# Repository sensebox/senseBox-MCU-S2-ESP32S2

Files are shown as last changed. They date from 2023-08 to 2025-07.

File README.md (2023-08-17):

# senseBoxMCU-S2 ESP32S2

# Erste Schritte

## Vorbereitung der Arduino IDE
Für den ESP32 werden von der Arduino-DIE zusätzliche Repositories benötigt:
Unter Datei -> Voreinstellungen muss unter Zusätzliche Boardverwalter-URLs 
```
https://raw.githubusercontent.com/espressif/arduino-esp32/gh-pages/package_esp32_dev_index.json
```
eingetragen werden. Anschließend muss unter Werkzeuge  Board: …  Boardverwalter… das Tool esp32 by Espressif Systems installiert werden.
Nachdem alles geladen wurde, muss man unter Werkzeuge das Board ESP32S2 Dev Module auswählen und USB CDC On Boot auf Enable stellen.
Zur Nutzung des UF2-Bootloaders müssen die UF2-Dateien von der Arduino-DIE erzeugt werden. Eine ausführliche Anleitung, wie die Arduino-IDE hierfür angepasst werden muss, findet sich unter
https://blog.adafruit.com/2021/09/17/automated-generation-of-bin-hex-uf2-files-for-arduino-continuous-integration/

### Installieren des UF2-Bootloaders
Eine Anleitung zur Installation des UF2-Bootloaders findet sich unter:
https://learn.adafruit.com/adafruit-metro-esp32-s2/install-uf2-bootloader

### Demo Codes

**Abstandssensor**
Es wird aus der Arduino-Bibliothek das Bifrost library for HC-SR04 Modul benötigt.
Es handelt sich hier um das angepasste Beispiel aus dem Modul, hier wurden lediglich die Pins für den IO2/IO3 Stecker angepasst und das Aktivieren der IO-Ports hinzugefügt.

**GPIO** 
Es werden keine besonderen Module benötigt.
Im Code werden die IO-Ports aktiviert und die beiden GPIOs 6 und 7 im Sekundentakt ein- und ausgeschaltet.

**IMU-Sensor ICM-20948**
Es wird zusätzlich das ICM20948_WE Modul benötigt
Dies ist das angepasste Modul aus der Beispielsammlung. Es wurden die I2C-IOs angepasst.

**Lichtsensor / Photo-Diode**
In diesem Beispiel wird die fest verbaute IN-S63DTLS analog gemessen. Besonders hier ist hier, dass PD_ENABLE Active-High ist, anstatt Active-Low wie in den anderen Beispielen.
Die Photodiode wird einmal pro Sekunde gemessen und der Bytewert ist über den seriellen Monitor von Arduino ausgebbar.
Die gemessene Spannung ist abhängig vom Photostrom der Photodiode:
V_Out=I_Photo/R
mit 
R=33kΩ
Bei normalem Umgebungslicht sollte der Bytewert etwa 200-500 betragen, bei direkter Sonneneinstrahlung liegt der Wert typisch bei 1000-2000. Bei direkter Bestrahlung mit einer weißen Hochleistungs-LED kann der Wert bis zum maximalen Wert von 4095 steigen. Die folgende Abbildung aus dem Datenblatt der Photodiode zeigt den Zusammenhang zwischen Lichtintensität und Photostrom:

**RGB-LED**
Es wird zusätzlich das Freenove_WS2812_Lib_for_ESP32 Modul benötigt.
Dieses Beispiel lässt die verbaute WS2812-LED im Sekundentakt alternativ rot, grün oder blau leuchten.

**SD-Card**
Das SD-Modul ist automatisch installiert.
Dieses ist das angepasste Beispiel aus dem Modul, es wurde die Aktivierung der Stromversorgung der SD-Karte hinzugefügt. Zusätzlich mussten die GPIOs für SPI angepasst werden.

**WLAN Client**
Das genutzte Wifi Modul ist automatisch installiert. 
Dieses Beispiel versucht eine WLAN-Verbindung aufzubauen und dann einen Webserver zu erreichen.

## Reset Button 
Das Board kann zurück in den Bootloader Modus gebracht werden, wenn der `Reset` Knopf gedrückt wird und der `Boot-Switch`-Button gleichzeitig gehalten wird.

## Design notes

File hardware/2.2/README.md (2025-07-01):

The following should be noted regarding these schematics:
- The chip name is  actually "ESP32-S2-MINI-1-N4R2"
- The UART_ENABLE Pin is not used anymore for enabeling the UART (UART is always enabled now). It is instead used internally for the PSRAM

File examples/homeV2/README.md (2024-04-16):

# HomeV2 Sketch Beta 

## Get started
 - Edit your ID's in the `ids.h` file 
 - Upload the sketch 
 - Let senseBox start and connect to its WiFi Access Point with the following credentials : SSID: `senseBox-AccessPoint` PW: `123456789`
 - With your connected device open `192.168.4.1` in your browser
 - Input your SSID and password into the form and click on "Verbinden" 
 - Your SSID and password will be uploaded onto the senseBox and saved on SD card (encrypted) the MCU should restart after some seconds and try to connect to the new WiFi 

## Future work 
 - Make sensors optional (i.e. work with #define statements)
 - Format to `.tpl` code for the templater
 - Have non SD version
 - Incorporate additional sensors

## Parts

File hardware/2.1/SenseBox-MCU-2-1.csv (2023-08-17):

Qty | Value | Device | Package | Parts | Description | BE# | CURRENT | DIELECTRIC | INDUCTANCE | POWER | TEMPERATURE_COEFFICIENT | TOLERANCE | VALUE | VOLTAGE
3 |  | PM_ASSEMBLY | PM1 | PM1, PM2, PM3 | Passing Marker | 0
2 | 0R | R_0R_0402N | 0402N | R4, R5 | Resistor | 1054 |  |  |  |  |  |  | 0R
1 | 0ZCH0150FF2E | FUSE-2PIN_1.5A_1210N | 1210N | F1 | Fuse with two Pins. | 2289 | 1.5 |  |  |  |  |  | 0ZCH0150FF2E
6 | 100K | R_100K_0402N | 0402N | R10, R11, R12, R14, R15, R16 | Resistor | 615 |  |  |  | 0.063 | 100 | 1% | 100K | 50
5 | 100n | C_100N_0402N | 0402N | C8, C16, C19, C20, C28 | Capacitor | 756 |  | X7R |  |  |  |  | 100n | 16
2 | 10K | RN4_10K_CAY16 | CAY16 | RN5, RN6 | Quad Resistor Net | 196 |  |  |  | 0.062 |  | 5% | 10K | 50
2 | 10K | R_10K_0402N | 0402N | R3, R13 | Resistor | 616 |  |  |  | 0.063 | 100 | 1% | 10K | 50
2 | 10n | C_10N_0402N | 0402N | C22, C27 | Capacitor | 617 |  | X7R |  |  |  |  | 10n | 25
2 | 12p | C_12P_0402N | 0402N | C14, C15 | Capacitor | 754 |  | NPO |  |  |  |  | 12p | 50
2 | 1K | R_1K_0402N | 0402N | R1, R18 | Resistor | 1088 |  |  |  | 0.063 | 100 | 1% | 1K | 50
2 | 1M | R_1M_0402N | 0402N | R8, R9 | Resistor | 1089 |  |  |  | 0.063 | 100 | 1% | 1M | 50
2 | 1X10-2.00-SMT | 1X10_2.00-SMT | 1X10-2.00-SMD | X10, X11 | Pin Header | 2288 |  |  |  |  |  |  | 1X10-2.00-SMT
3 | 1u | C_1U_0402N | 0402N | C9, C12, C13 | Capacitor | 901 |  | X5R |  |  |  |  | 1u | 10
1 | 1u | L_WE-LQS-1U_5040 | 5040 | L1 | Inductor | 2282 | 4.9 |  | 1u |  |  |  | 1u
5 | 22u | C_22U_0805N | 0805N | C1, C2, C7, C17, C18 | Capacitor | 208 |  | X5R |  |  |  |  | 22u | 6V3
1 | 2K | R_2K_0402N | 0402N | R2 | Resistor | 1057 |  |  |  | 0.063 | 100 | 1% | 2K | 50
1 | 2n2 | C_2N2_0402N | 0402N | C21 | Capacitor | 752 |  | X7R |  |  |  |  | 2n2 | 50
1 | 32K768 | CRYSTAL-1GND_1.4X1.5X5.2 | 1.4X1.5X5.2 | XT1 | Crystal with one Ground Terminal | 830 |  |  |  |  |  |  | 32K768
3 | 330R | RN4_330R_CAY16 | CAY16 | RN1, RN3, RN4 | Quad Resistor Net | 483 |  |  |  | 0.062 |  | 5% | 330R | 50
1 | 33K | R_33K_0402N | 0402N | R17 | Resistor | 1428 |  |  |  | 0.063 | 100 | 1% | 33K | 50
1 | 452403012014 | DPDT_WS-SLSV | WS-SLSV | SW1 | Switch - Double Pole, Double Throw | 2294 |  |  |  |  |  |  | 452403012014
6 | 4u7 | C_4U7_0603N | 0603N | C3, C4, C5, C6, C26, C29 | Capacitor | 284 |  | X5R |  |  |  |  | 4u7 | 6V3
2 | 5K1 | R_5K1_0402N | 0402N | R6, R7 | Resistor | 2285 |  |  |  | 0.063 | 100 | 1% | 5K1 | 50
1 | 7427927291 | L_WE-CBF-7427927291_0402N | 0402N | L2 | Inductor | 1925 | 0.3 |  |  |  |  |  | 7427927291
1 | 82400152 | TVS-3-CHANNELS_WE-TVS_SOT563 | SOT563 | D3 | TVS Suppressor Diodes Array | 2015 |  |  |  |  |  |  | 82400152
1 | B4B-PH-SM4-TB | SH-02_B4B-PH-SM4-TB_B4B-PH-SM4-TB | B4B-PH-SM4-TB | X2 | SH Connector | 2370 |  |  |  |  |  |  | B4B-PH-SM4-TB
1 | BE_LOGO_10MM_T | BE_LOGO_10MM_T | BE_TOP_10MM | U$3 | Budelmann Elektronik Logo for pcb print in different sizes. | 0
1 | BM02B-SRSS | SH-02_BM02B-SRSS_BM02B-SRSS | BM02B-SRSS | X9 | SH Connector | 2286 |  |  |  |  |  |  | BM02B-SRSS
6 | BM04B-SRSS | SH-04_BM04B-SRSS_BM04B-SRSS | BM04B-SRSS | X3, X4, X5, X6, X7, X8 | SH Connector | 2287 |  |  |  |  |  |  | BM04B-SRSS
1 | BM05B-SRSS | SH-05_BM05B-SRSS_BM05B-SRSS | BM05B-SRSS | IC9 | SH Connector | 2369 |  |  |  |  |  |  | BM05B-SRSS
2 | DZDH0401DW-7 | DZDH0401DW | SOT363 | IC4, IC5 | Ideal Diode Controller | 2290 |  |  |  |  |  |  | DZDH0401DW-7
1 | ESP32-S2-MINI-1-N4 | ESP32-S2-MINI_ESP32-S2-MINI-1-N4_ESP32-S2-MINI | ESP32-S2-MINI | IC3 | 2.4 GHz Wi-Fi (802.11 b/g/n) module built around ESP32-S2 series of SoCs, Xtensa Single Core 32-bit LX7 Microprocessor | 2275 |  |  |  |  |  |  | ESP32-S2-MINI-1-N4
1 | ICM-42670-P | ICM-42670-P_LGA14_2.5X3 | LGA14_2.5X3 | IC8 | high performance 6-axis MEMS MotionTracking IMU | 2357 |  |  |  |  |  |  | ICM-42670-P
1 | IN-S63DTLS | PHOTODIODE_IN-S63DTLS_0603N | 0603N | D5 | Photo diode | 2296 |  |  |  |  |  |  | IN-S63DTLS
1 | LM66200DRLR | LM66200 | SOT-5X3 | D2 | LM66200 1.6-5V, 2.5A Dual Ideal Diode with Automatic Switchover | 2291 |  |  |  |  |  |  | LM66200DRLR
1 | MCP73831T-2ACI/OT | MCP73831_MCP73831T-2ACI/OT_SOT23-5 | SOT23-5 | IC2 | Miniature Single-Cell, Fully Integrated Li-Ion, Li-Polymer Charge Management Controllers up to 500mA | 2283 |  |  |  |  |  |  | MCP73831T-2ACI/OT
1 | MEM2051-00-195-00-A | SD-CARD2_MEM2051 | MEM2051 | X12 | SD Card with Card Detection (Single Pin Contacting GND) | 2293 |  |  |  |  |  |  | MEM2051-00-195-00-A
1 | MPU-6050 | MPU-6050 | QFN24_4X4 | IC6 | 6-Axis Inertial Measurement Unit Combining a 3-Axis Gyroscope and a 3-Axis Accelerometer | 2297 |  |  |  |  |  |  | MPU-6050
1 | NX3008NBKS | MOSFET-N-DUAL_NX3008NBKS_SOT363 | SOT363 | Q6 | Dual Mosfet | 405 | 0.35 |  |  | 0.3 |  |  | NX3008NBKS | 30
4 | PMV48XP | MOSFET-P_PMV48XP_SOT23' | SOT23 | Q2, Q3, Q4, Q5 | Single P-Channel Mosfet | 271 | 3.5 |  |  |  |  |  | PMV48XP | 20
1 | RP602Z330C-E2-F | RP602_RP602Z330C-E2-F_WLCSP-20-P1 | WLCSP-20-P1 | IC1 | 1.5 A PWM/VFM Buck-Boost DC/DC Converter with Synchronous Rectifier | 2281 |  |  |  |  |  |  | RP602Z330C-E2-F
1 | SIA911ADJ-T1-GE3 | MOSFET-P-DUAL_SIA911ADJ-T1-GE3_POWERPAK-SC70-6 | POWERPAK-SC70-6 | Q1 | Dual Mosfet with Common Drain Pins | 2292 | 4.5 |  |  |  |  |  | SIA911ADJ-T1-GE3 | 20
1 | USB4105-GF-A | USB-C-2.0_USB4105-GF-A_USB4105 | USB4105 | X1 | USB-C Connector with USB 2.0 Support | 2284 |  |  |  |  |  |  | USB4105-GF-A
1 | WS-TASU | TACTILE_SWITCH_WS-TASU | WS-TASU | SW3 | Tactile Switch | 778 |  |  |  |  |  |  | WS-TASU
1 | WS-TRS-6x3.5 | TACTILE_SWITCH_WS-TRS-6X3.5 | WS-TRS-6X3.5 | SW2 | Tactile Switch | 272 |  |  |  |  |  |  | WS-TRS-6x3.5
1 | WS2812B | LED-ADRESSABLE_WS2812B_5050 | 5050 | D4 | Adressable LED with Data-In and Data-Out Pins | 2295 |  |  |  |  |  |  | WS2812B
1 | green | LED_GREEN_0603N | 0603N | D6 | Single LED | 223 |  |  |  |  |  |  | green
2 | opt | C_0402N | 0402N | C10, C11 | Capacitor | 0 |  |  |  |  |  |  | opt
1 | red | LED_RED_0603N | 0603N | D1 | Single LED | 224 |  |  |  |  |  |  | red

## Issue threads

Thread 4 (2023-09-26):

MPU6050 occasionally gives status 2 or 5

PaulaScharf, 2023-09-26:
The onboard mpu occasionally gives status 2 or 5 after the MCU was restarted. This happens with both the MPU6050 and the MPU6050_light library. It is solved by replugging the usb cable between computer and MCU.
The status codes come from the endTransmission call from the Wire library:
status 2: received NACK on transmit of address
status 5: timeout

PaulaScharf, 2023-10-11:
This seems to have been an issue cause by the [MPU6050_light](https://github.com/rfetick/MPU6050_light) library. It doesnt (or rarely) occurs with for example the [Adafruit_MPU6050](https://github.com/adafruit/Adafruit_MPU6050) library.

Closed 2023-10-11.

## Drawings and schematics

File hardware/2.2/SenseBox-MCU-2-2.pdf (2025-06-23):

# and On/Off-Switch USB

A

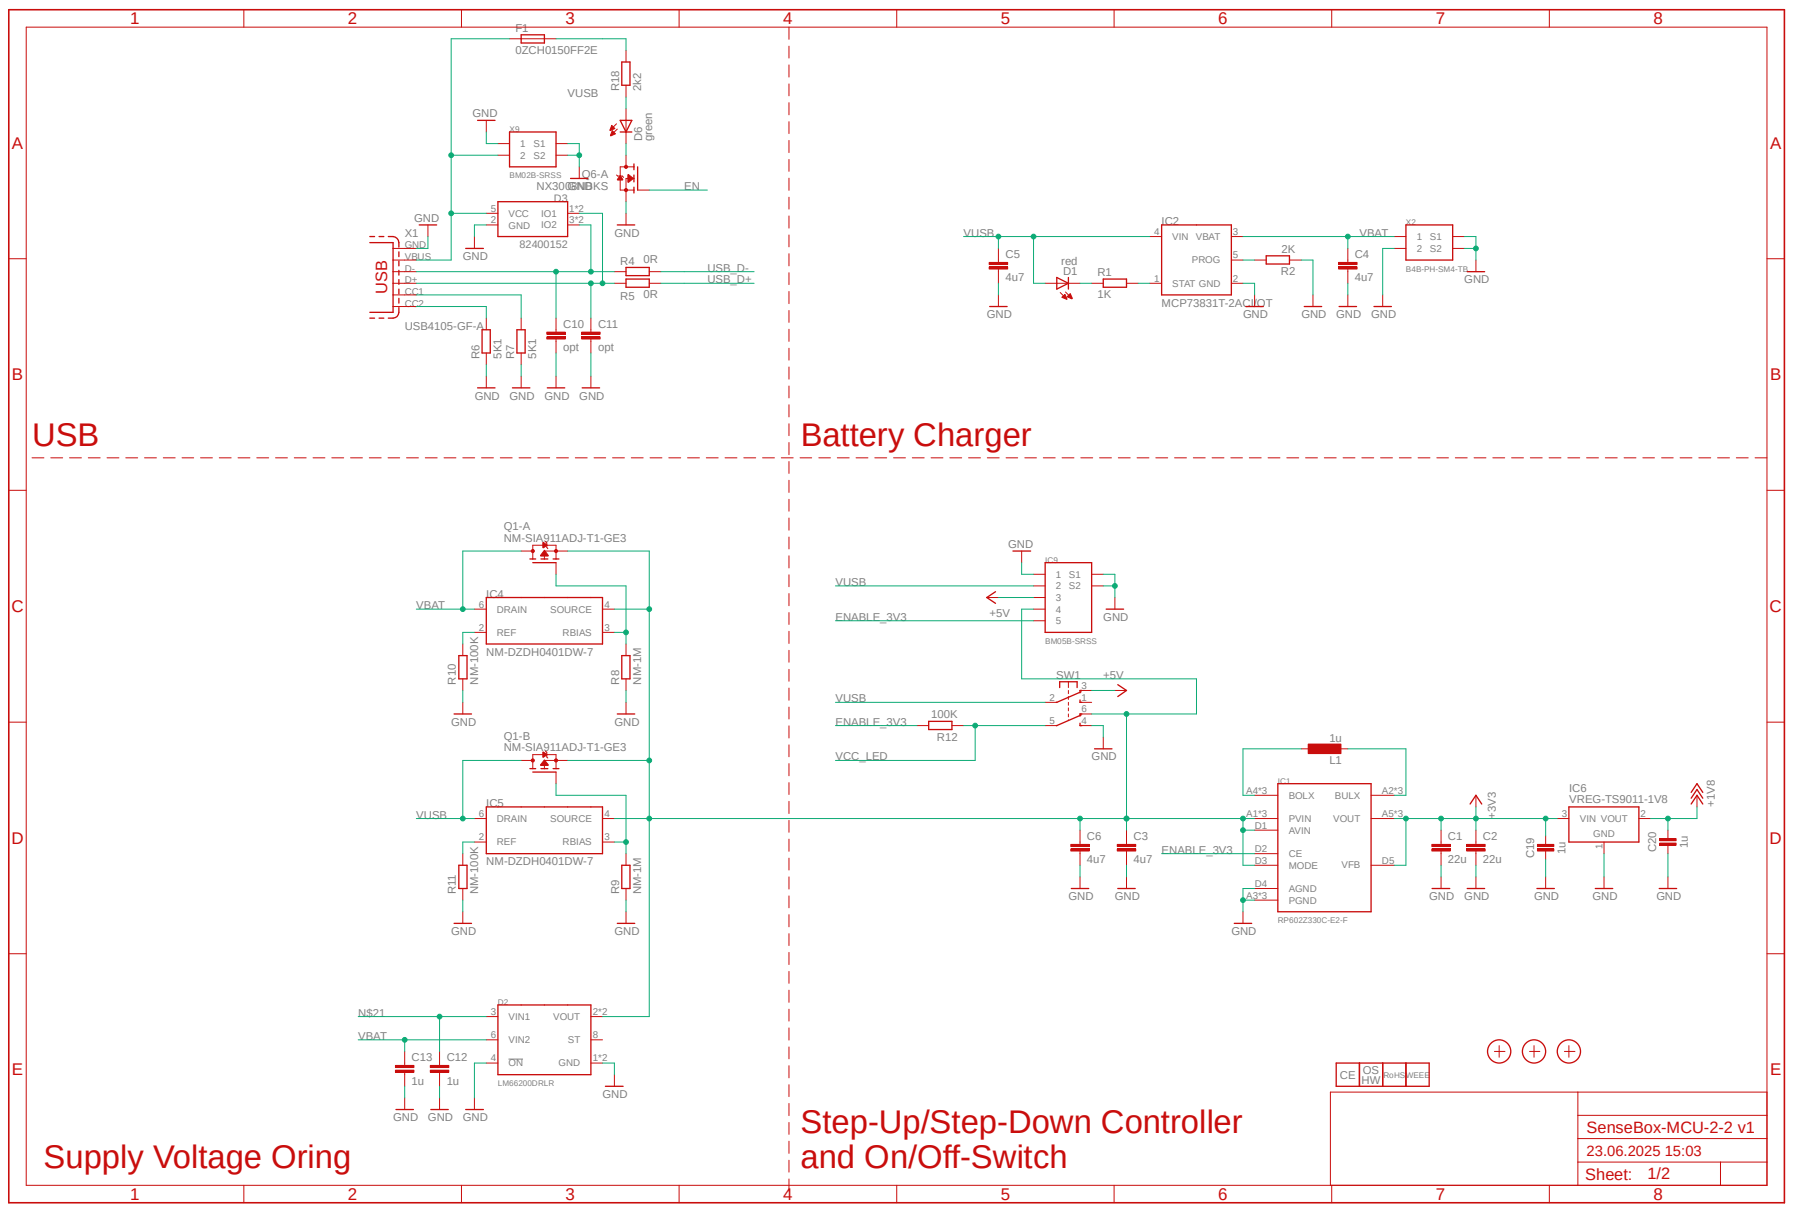
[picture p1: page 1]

D+
CC1

Step-Up/Step-Down Controller

# 1u ¹⁰K ⁺³V³ GND

# GND ¹⁰K ⁺³V³ PMV⁴⁸XP22u

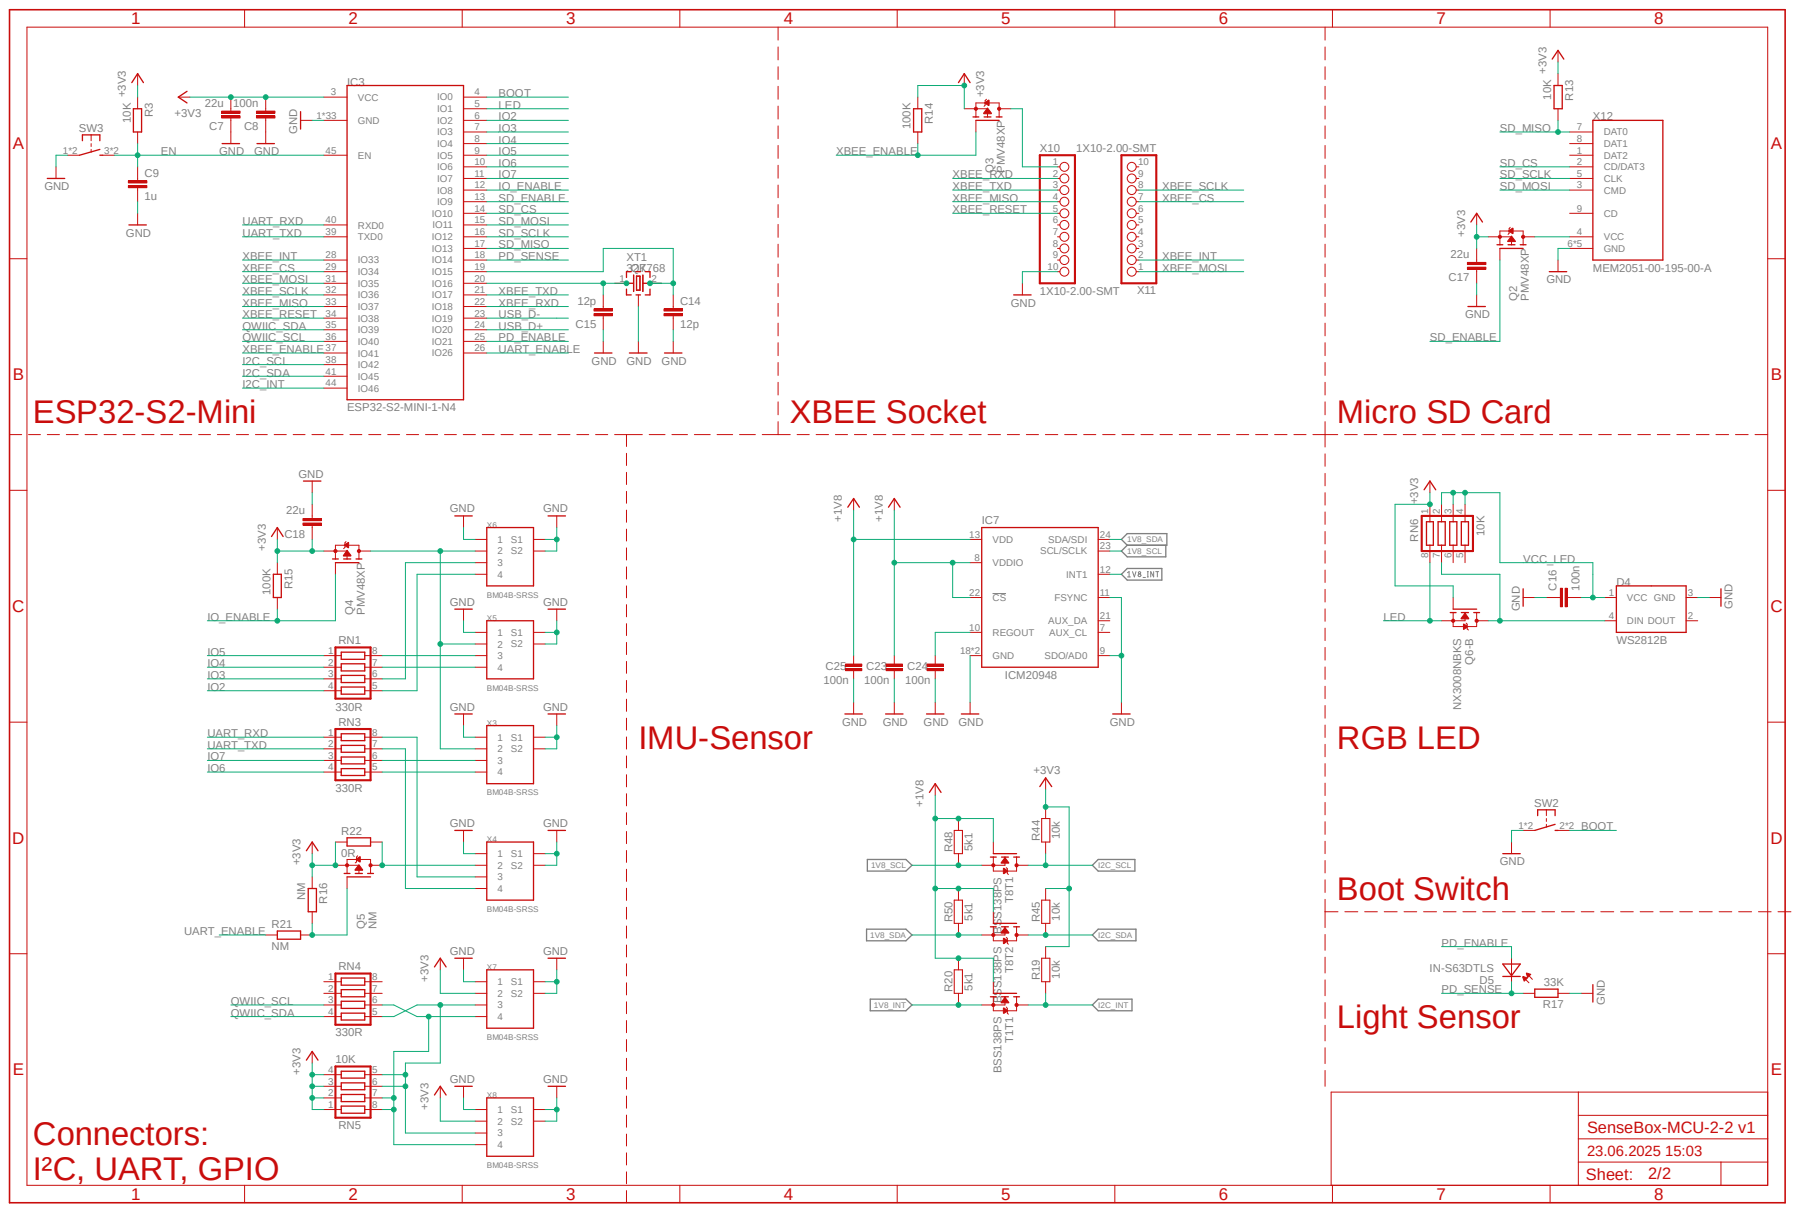
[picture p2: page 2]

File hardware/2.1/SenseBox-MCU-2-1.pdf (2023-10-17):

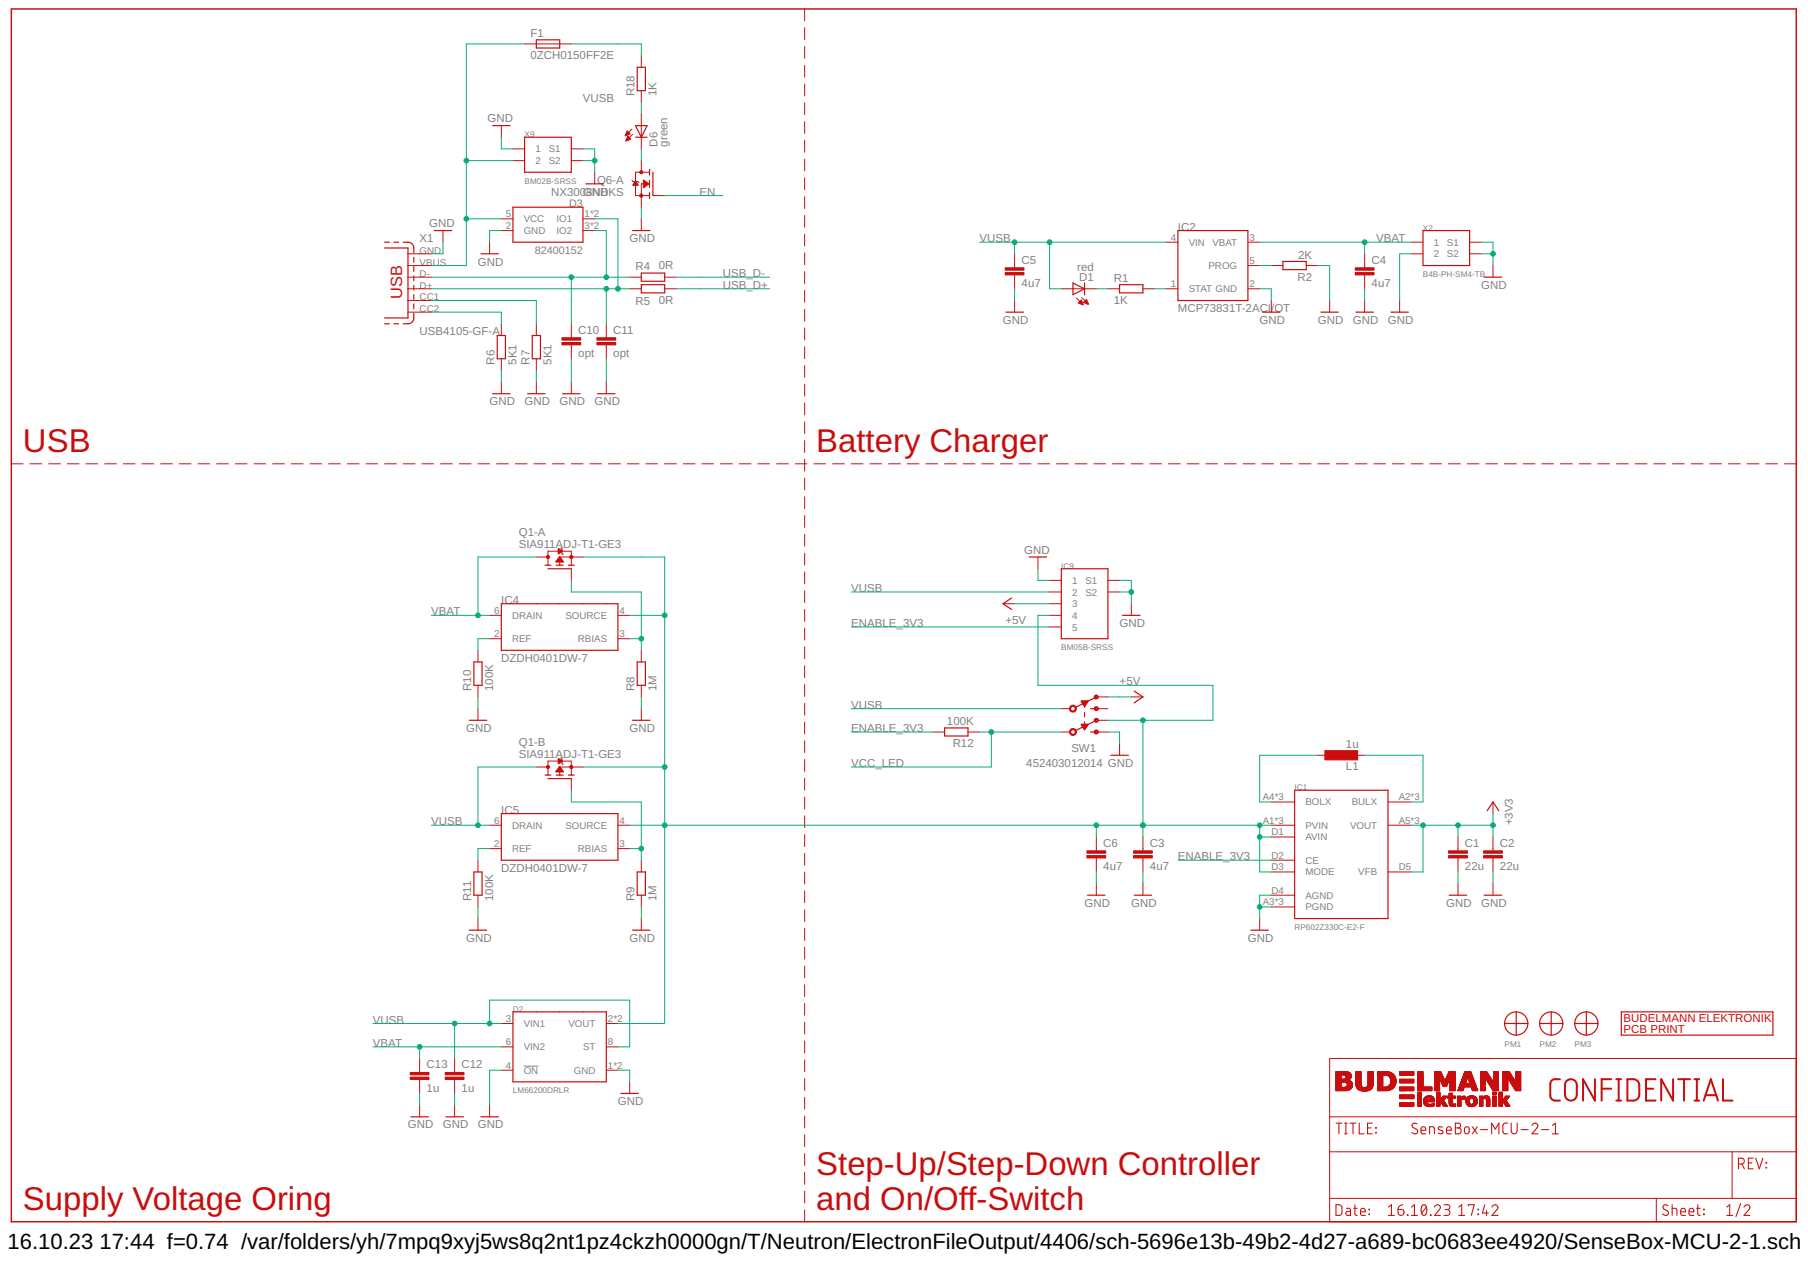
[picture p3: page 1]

B4B-PH-SM4-TBGND GND GND

Step-Up/Step-Down Controller
and On/Off-Switch

16.10.23 17:44 f=0.74 /var/folders/yh/7mpq9xyj5ws8q2nt1pz4ckzh0000gn/T/Neutron/ElectronFileOutput/4406/sch-5696e13b-49b2-4d27-a689-bc0683ee4920/SenseBox-MCU-2-1.sch (Sheet: 1/2)

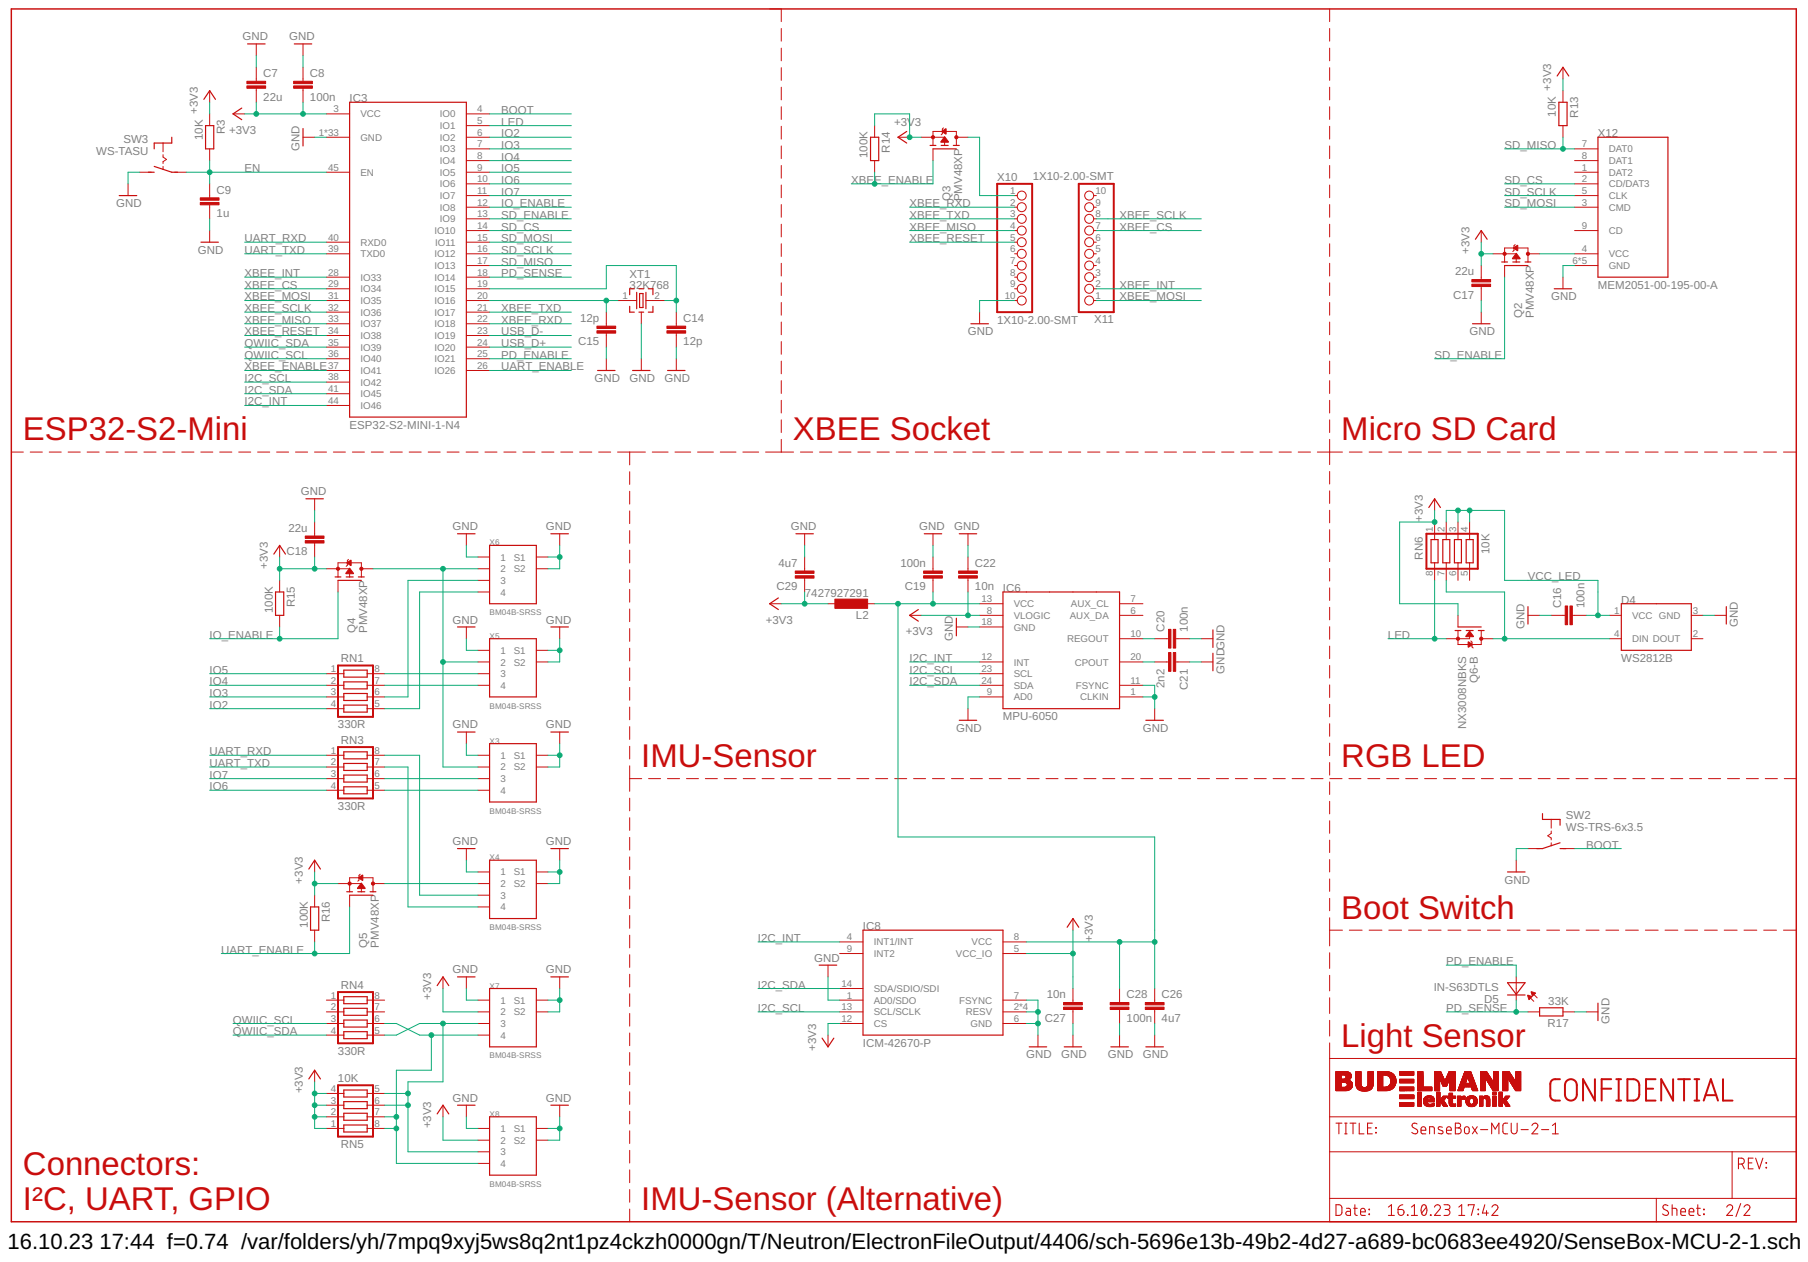
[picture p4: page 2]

+3V3 GND GND GND GND GND GND

16.10.23 17:44 f=0.74 /var/folders/yh/7mpq9xyj5ws8q2nt1pz4ckzh0000gn/T/Neutron/ElectronFileOutput/4406/sch-5696e13b-49b2-4d27-a689-bc0683ee4920/SenseBox-MCU-2-1.sch (Sheet: 2/2)

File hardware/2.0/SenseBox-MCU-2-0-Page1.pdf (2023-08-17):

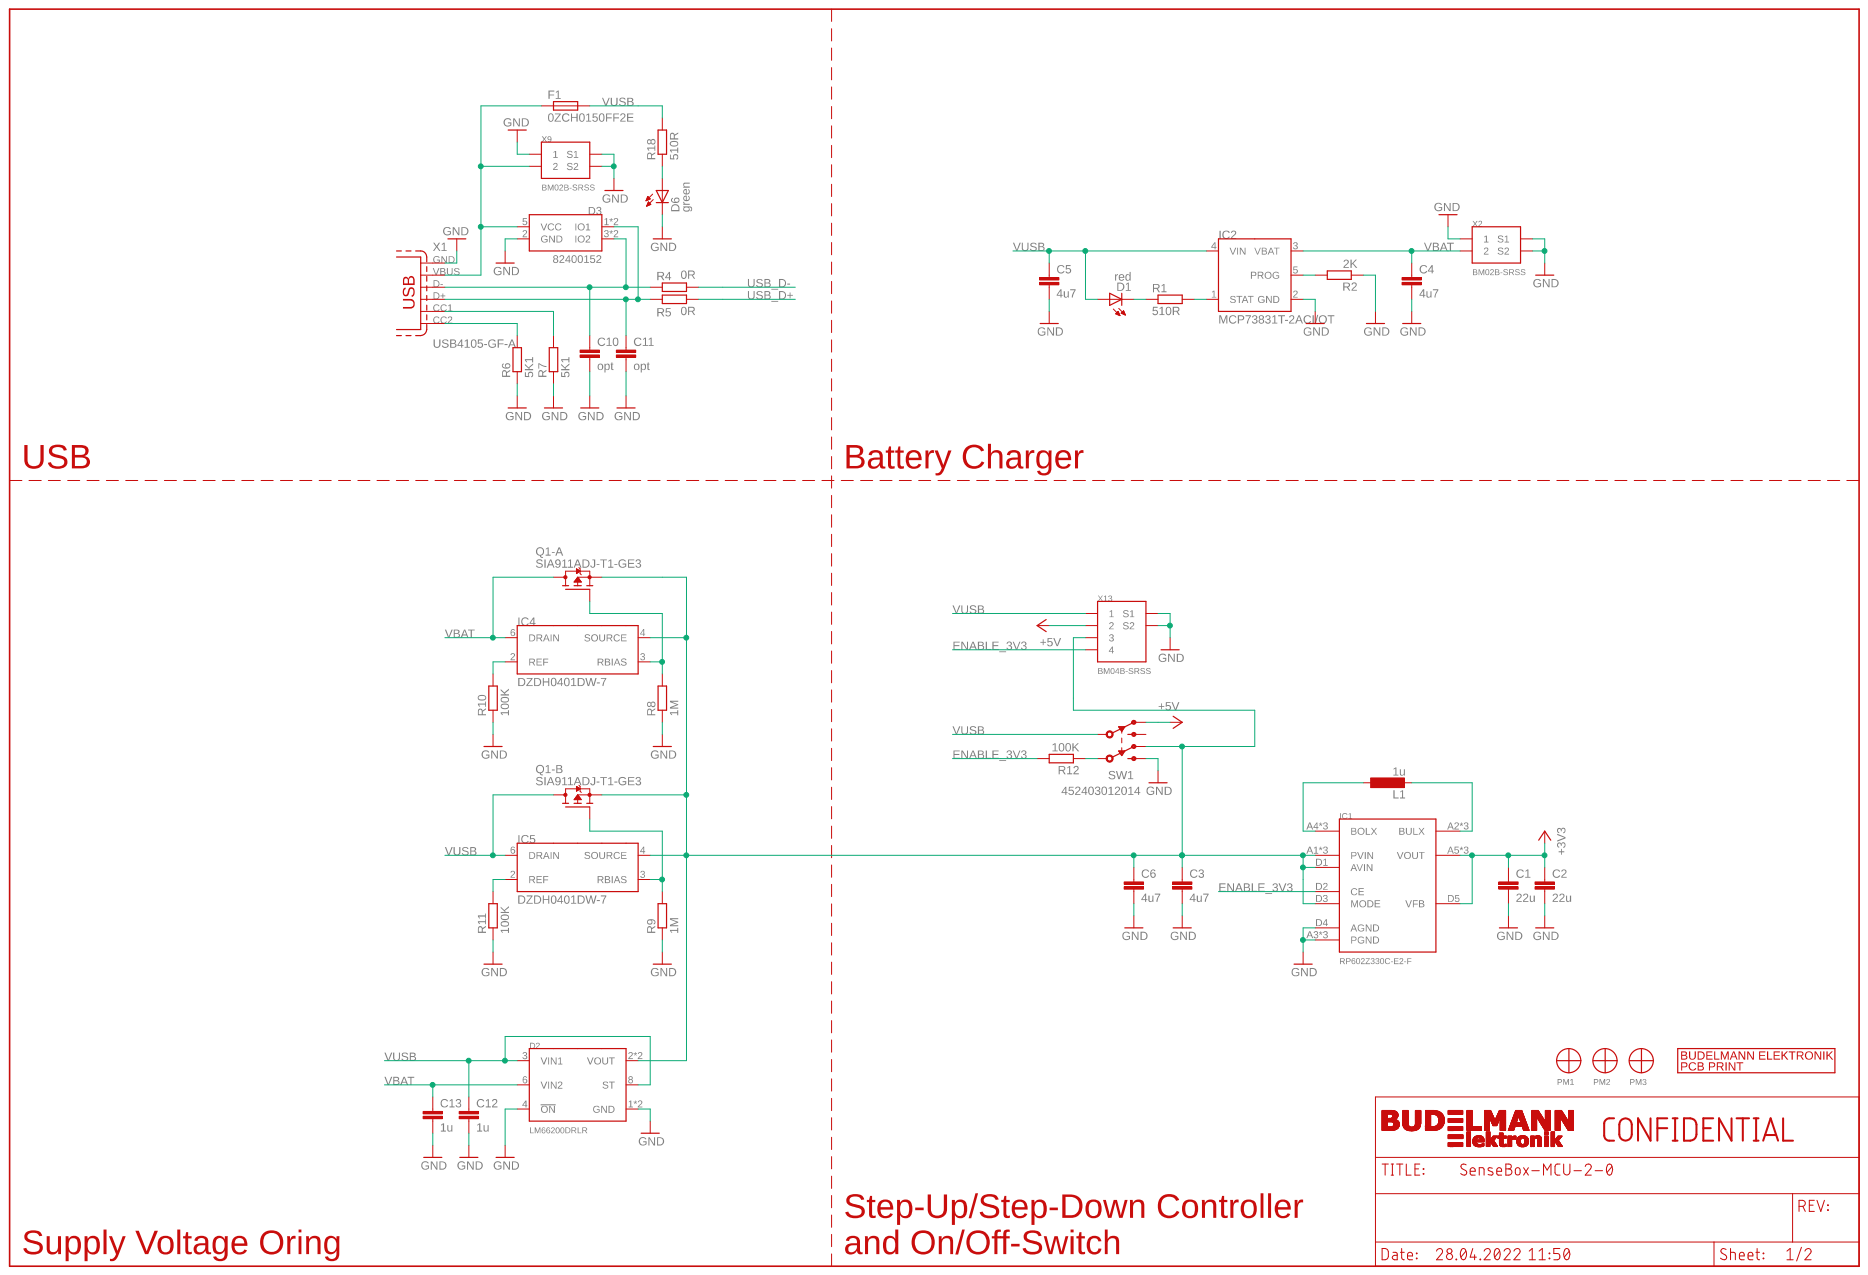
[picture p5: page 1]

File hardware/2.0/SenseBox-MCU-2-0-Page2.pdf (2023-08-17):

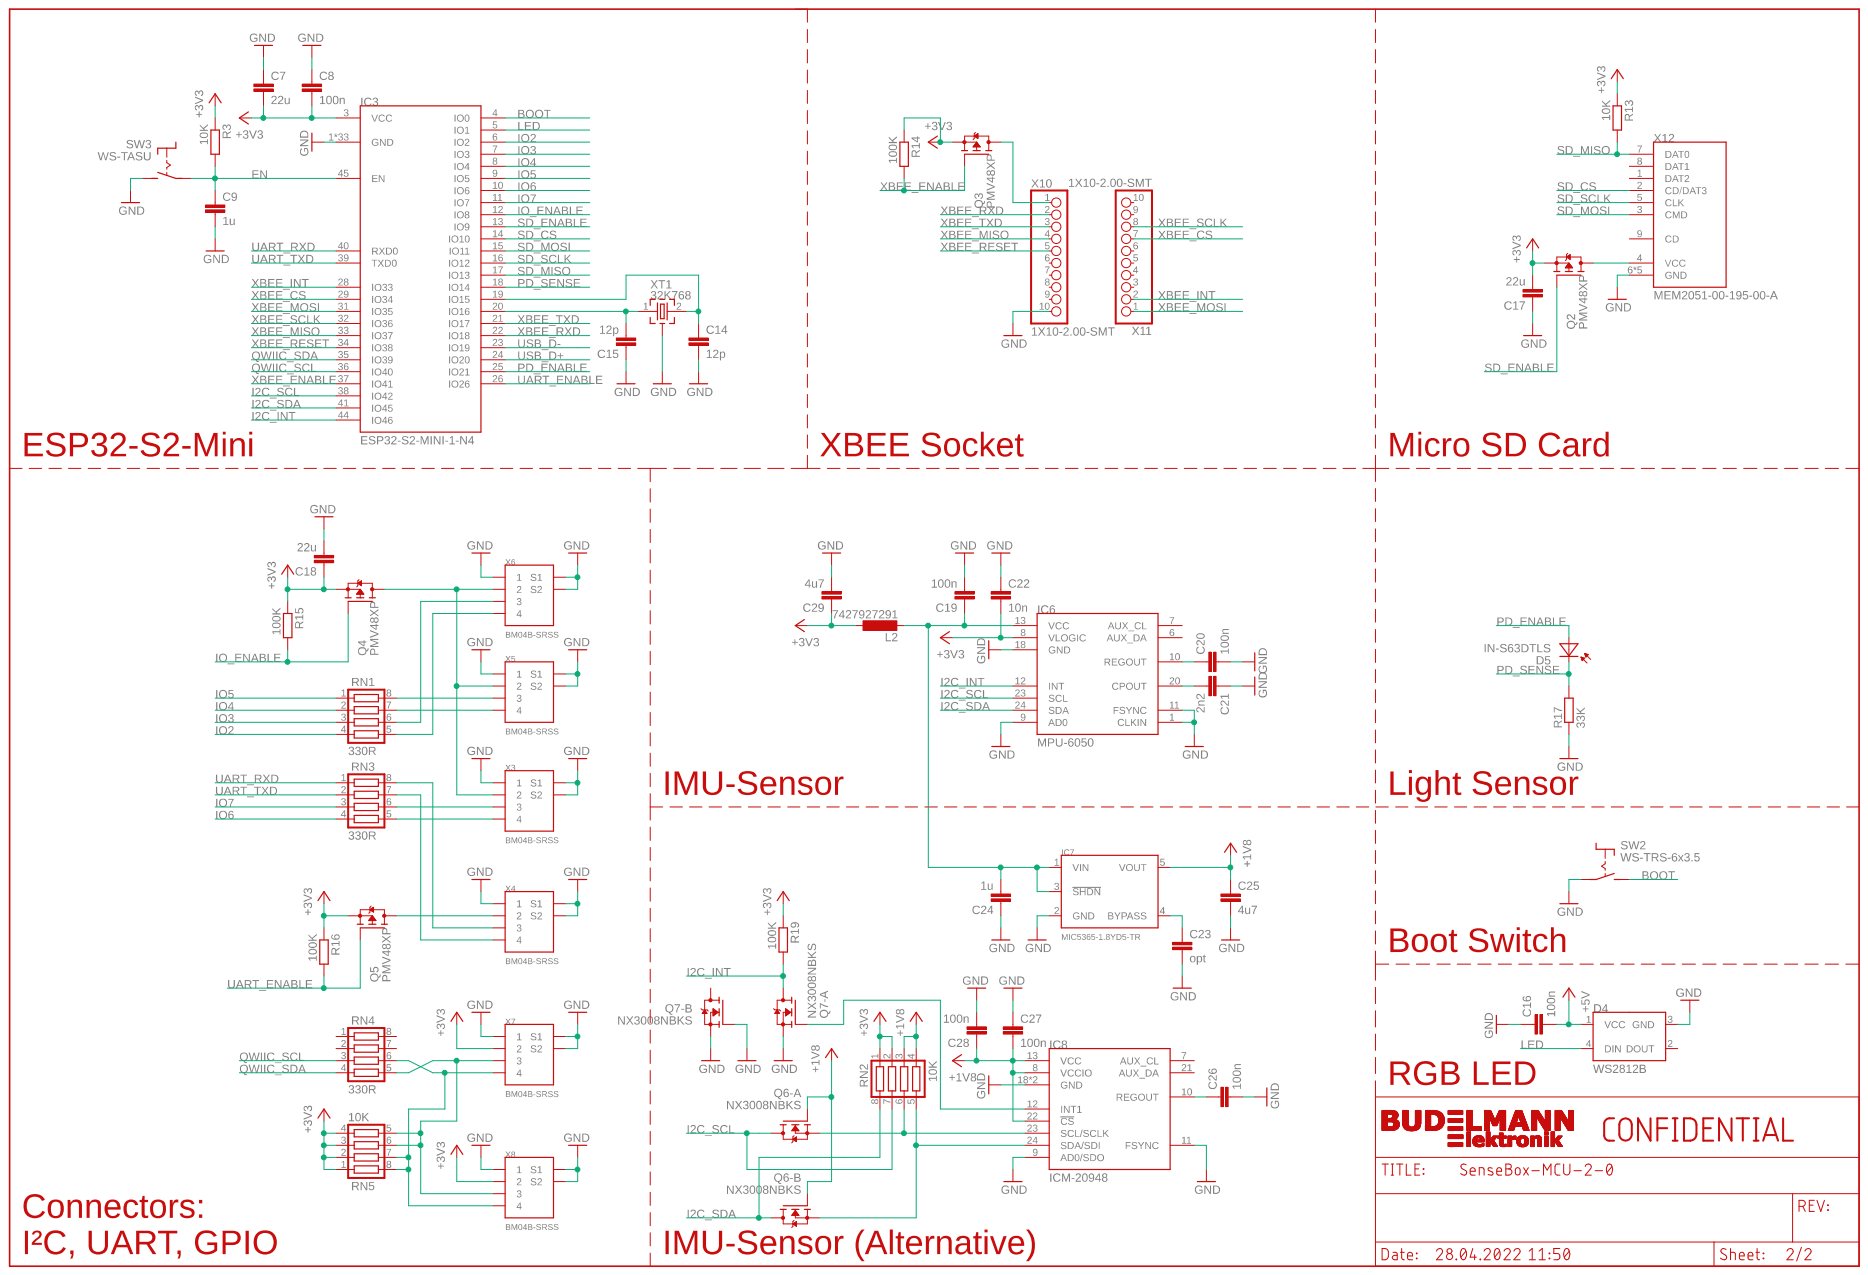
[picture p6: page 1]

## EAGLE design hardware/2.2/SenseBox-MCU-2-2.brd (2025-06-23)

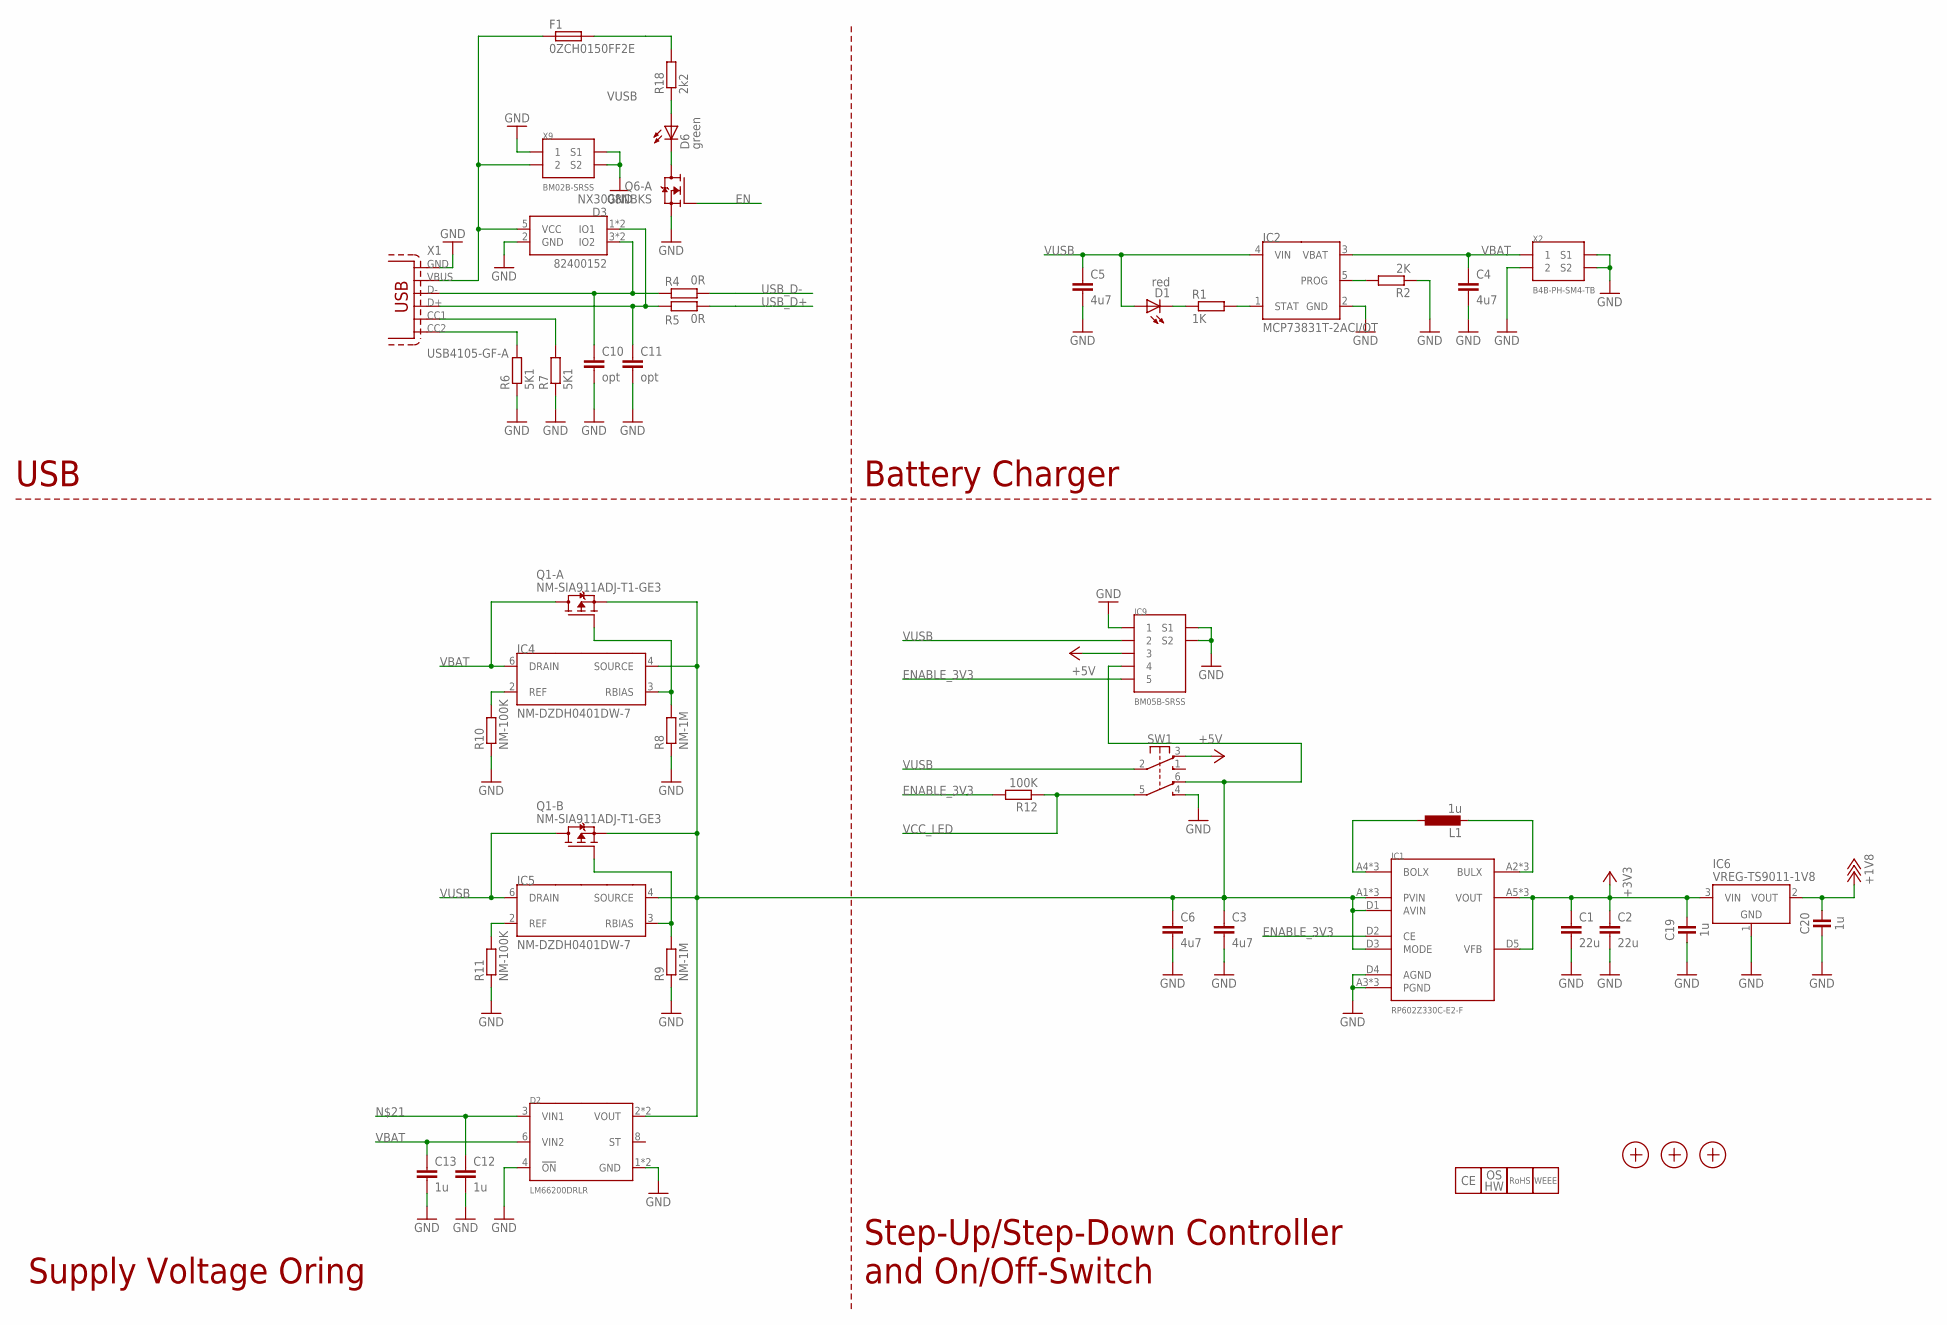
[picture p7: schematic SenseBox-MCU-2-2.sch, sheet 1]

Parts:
C1, C2: 22u; 0805N
C3, C4, C5, C6: 4u7; 0603N
C10, C11: opt; 0402N
C12, C13: 1u; 0402N
C19, C20: 1u; C0402
D1: red; 0603N
D2: LM66200DRLR; SOT-5X3
D3: 82400152; SOT563
D6: green; 0603N
F1: 0ZCH0150FF2E; 1210N
IC1: RP602Z330C-E2-F; WLCSP-20-P1
IC2: MCP73831T-2ACI/OT; SOT23-5
IC4, IC5: NM-DZDH0401DW-7; SOT363
IC6: VREG-TS9011-1V8; SOT23
IC9: BM05B-SRSS
L1: 1u; 5040
LOGO1: LOGO_CE-2; CE_2MM
LOGO2: LOGO_OSHW-2; OSHW_2MM
LOGO3: LOGO_ROHS-2; ROHS_2MM
LOGO4: LOGO_WEEE-4; WEEE_4MM
Q1: NM-SIA911ADJ-T1-GE3; POWERPAK-SC70-6
Q6: NX3008NBKS; SOT363
R1: 1K; 0402N
R2: 2K; 0402N
R4, R5: 0R; 0402N
R6, R7: 5K1; 0402N
R8, R9: NM-1M; 0402N
R10, R11: NM-100K; 0402N
R12: 100K; 0402N
R18: 2k2; 0402N
SW1: SW-2UM-CUS22B; CUS22B
X1: USB4105-GF-A; USB4105
X2: B4B-PH-SM4-TB
X9: BM02B-SRSS
X13, X14, X15: PASSER-07; PASSER_07MM

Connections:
+1V8: C20.2, IC6.2 (VOUT); also elsewhere on the board
+3V3: C1.1, C2.1, C19.2, IC1.A5 (VOUT), IC1.B5 (VOUT), IC1.C5 (VOUT), IC1.D5 (VFB), IC6.3 (VIN); also elsewhere on the board
+5V: IC9.3, SW1.3 (NC1)
EN: Q6.2 (G); also elsewhere on the board
ENABLE_3V3: IC1.D2 (CE), IC9.5, R12.2
GND: C1.2, C2.2, C3.2, C4.2, C5.2, C6.2, C10.2, C11.2, C12.2, C13.2, C19.1, C20.1, D2.1 (GND), D2.4 (!ON), D2.5 (GND), D3.2 (GND), IC1.A3 (PGND), IC1.B3 (PGND), IC1.C3 (PGND), IC1.D4 (AGND), IC2.2 (GND), IC6.1 (GND), IC9.1, IC9.S1, IC9.S2, Q6.1 (S), R2.1, R6.1, R7.1, R8.1, R9.1, R10.1, R11.1, SW1.4 (NO2), X1.A1_B12 (GND), X1.B1_A12 (GND), X1.S1 (GND), X1.S2 (GND), X1.S3 (GND), X1.S4 (GND), X2.2, X2.SH1 (S1), X2.SH2 (S2), X9.1, X9.S1, X9.S2; also elsewhere on the board
unnamed: IC1.A4 (BOLX), IC1.B4 (BOLX), IC1.C4 (BOLX), L1.1
unnamed: IC1.A2 (BULX), IC1.B2 (BULX), IC1.C2 (BULX), L1.2
unnamed: IC2.5 (PROG), R2.2
unnamed: IC4.2 (REF), R10.2
unnamed: D1.C, R1.1
unnamed: IC2.1 (STAT), R1.2
unnamed: C10.1, D3.3 (IO2), D3.4 (IO2), R4.1, X1.A7 (D-), X1.B7 (D-)
unnamed: C11.1, D3.1 (IO1), D3.6 (IO1), R5.1, X1.A6 (D+), X1.B6 (D+)
unnamed: R6.2, X1.B5 (CC2)
unnamed: R7.2, X1.A5 (CC1)
unnamed: D3.5 (VCC), F1.1 (2), X1.A4_B9 (VBUS), X1.B4_A9 (VBUS), X9.2
unnamed: IC5.2 (REF), R11.2
unnamed: IC4.3 (RBIAS), Q1.2 (G), R8.2
unnamed: C3.1, C6.1, D2.2 (VOUT), D2.7 (VOUT), IC1.A1 (PVIN), IC1.B1 (PVIN), IC1.C1 (PVIN), IC1.D1 (AVIN), IC1.D3 (MODE), IC4.4 (SOURCE), IC5.4 (SOURCE), IC9.4, Q1.1 (S), Q1.4 (S), SW1.6 (NC2)
unnamed: IC5.3 (RBIAS), Q1.5 (G), R9.2
unnamed: C12.1, D2.3 (VIN1)
unnamed: D6.A, R18.1
unnamed: D6.C, Q6.6 (D)
USB_D+: R5.2; also elsewhere on the board
USB_D-: R4.2; also elsewhere on the board
VBAT: C4.1, C13.1, D2.6 (VIN2), IC2.3 (VBAT), IC4.6 (DRAIN), Q1.6 (D), Q1.7 (D), X2.1
VCC_LED: R12.1, SW1.5 (C2); also elsewhere on the board
VUSB: C5.1, D1.A, F1.2 (3), IC2.4 (VIN), IC5.6 (DRAIN), IC9.2, Q1.3 (D), Q1.8 (D), R18.2, SW1.2 (C1)

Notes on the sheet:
USB
Battery Charger
Supply Voltage Oring
Step-Up/Step-Down Controller and On/Off-Switch

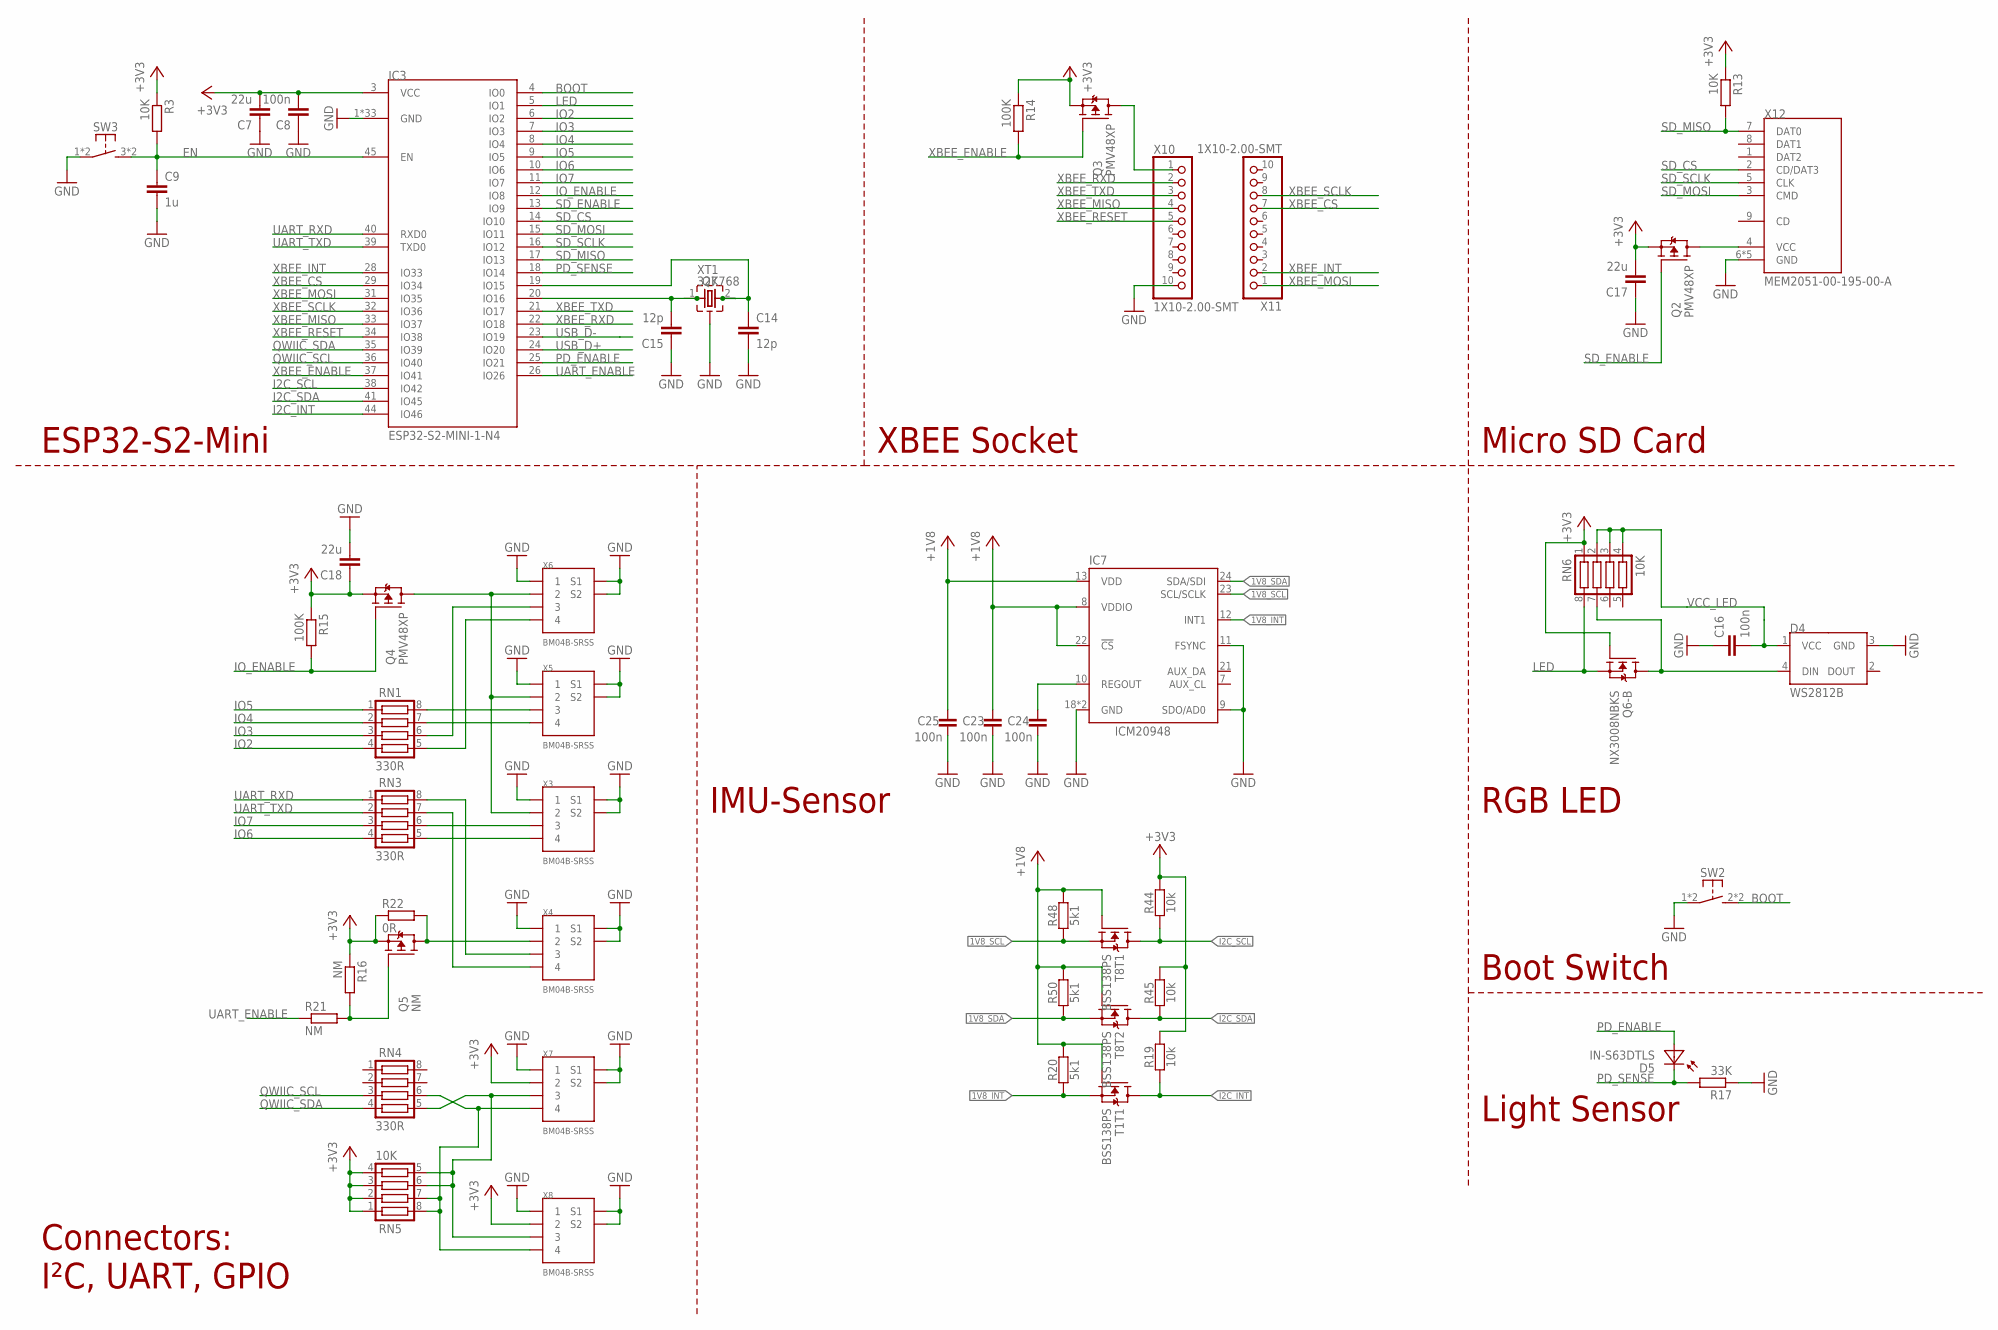
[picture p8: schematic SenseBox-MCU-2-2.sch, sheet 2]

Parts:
C7, C17, C18: 22u; 0805N
C8, C16: 100n; 0402N
C9: 1u; 0402N
C14, C15: 12p; 0402N
C23, C24, C25: 100n; C0402
D4: WS2812B; 5050
D5: IN-S63DTLS; 0603N
IC3: ESP32-S2-MINI-1-N4; ESP32-S2-MINI
IC7: ICM20948; QFN24-3X3
Q2, Q3, Q4: PMV48XP; SOT23
Q5: NM; SOT23
Q6: NX3008NBKS; SOT363
Q7: CRYSTAL-ZM315; CRYSTAL_ZM315
R3, R13: 10K; 0402N
R14, R15: 100K; 0402N
R16, R21: NM; 0402N
R17: 33K; 0402N
R19, R44, R45: 10k; C0402
R20, R48, R50: 5k1; C0402
R22: 0R; 0402N
RN1, RN3, RN4: 330R; CAY16
RN5, RN6: 10K; CAY16
SW2: SW-TACTILE-TL3365; TL3365
SW3: SW-TACTILE-PTS840P; PTS840P
T1, T8: BSS138PS; SOT363
X3, X4, X5, X6, X7, X8: BM04B-SRSS
X10, X11: 1X10-2.00-SMT; 1X10-2.00-SMD
X12: MEM2051-00-195-00-A; MEM2051
XT1: 32K768; 1.4X1.5X5.2

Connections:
1V8_INT: IC7.12 (INT1), R20.1, T1.1 (S)
1V8_SCL: IC7.23 (SCL/SCLK), R48.1, T8.1 (S)
1V8_SDA: IC7.24 (SDA/SDI), R50.1, T8.4 (S)
+1V8: C23.2, C25.2, IC7.8 (VDDIO), IC7.13 (VDD), IC7.22 (!CS), R20.2, R48.2, R50.2, T1.2 (G), T8.2 (G), T8.5 (G); also elsewhere on the board
+3V3: C7.2, C8.2, C17.2, C18.1, IC3.3 (VCC), Q2.2 (S), Q3.2 (S), Q4.2 (S), Q5.2 (S), Q6.5 (G), R3.1, R13.1, R14.1, R15.1, R16.1, R19.2, R22.1, R44.2, R45.2, RN5.1, RN5.2, RN5.3, RN5.4, RN6.1, X7.2, X8.2; also elsewhere on the board
BOOT: IC3.4 (IO0), SW2.2 (S1), SW2.3 (S1)
EN: C9.1, IC3.45 (EN), R3.2, SW3.3 (S1), SW3.4 (S1); also elsewhere on the board
GND: C7.1, C8.1, C9.2, C14.2, C15.1, C16.1, C17.1, C18.2, C23.1, C24.1, C25.1, D4.3 (GND), IC3.1 (GND), IC3.2 (GND), IC3.30 (GND), IC3.42 (GND), IC3.43 (GND), IC3.46 (GND), IC3.47 (GND), IC3.48 (GND), IC3.49 (GND), IC3.50 (GND), IC3.51 (GND), IC3.52 (GND), IC3.53 (GND), IC3.54 (GND), IC3.55 (GND), IC3.56 (GND), IC3.57 (GND), IC3.58 (GND), IC3.59 (GND), IC3.60 (GND), IC3.61 (GND), IC3.62 (GND), IC3.63 (GND), IC3.64 (GND), IC3.65 (GND), IC3.66 (GND), IC3.67 (GND), IC3.68 (GND), IC3.69 (GND), IC3.70 (GND), IC3.71 (GND), IC3.72 (GND), IC3.73 (GND), IC7.9 (SDO/AD0), IC7.11 (FSYNC), IC7.18 (GND), IC7.20 (GND), R17.1, SW2.1, SW2.4 (P1), SW3.1, SW3.2 (P1), X3.1, X3.S1, X3.S2, X4.1, X4.S1, X4.S2, X5.1, X5.S1, X5.S2, X6.1, X6.S1, X6.S2, X7.1, X7.S1, X7.S2, X8.1, X8.S1, X8.S2, X10.10, X12.6 (GND), X12.S1 (GND), X12.S2 (GND), X12.S3 (GND), X12.S4 (GND), XT1.3 (GND); also elsewhere on the board
I2C_INT: IC3.44 (IO46), R19.1, T1.6 (D)
I2C_SCL: IC3.38 (IO42), R44.1, T8.6 (D)
I2C_SDA: IC3.41 (IO45), R45.1, T8.3 (D)
IO2: IC3.6 (IO2), RN1.4
IO3: IC3.7 (IO3), RN1.3
IO4: IC3.8 (IO4), RN1.2
IO5: IC3.9 (IO5), RN1.1
IO6: IC3.10 (IO6), RN3.4
IO7: IC3.11 (IO7), RN3.3
IO_ENABLE: IC3.12 (IO8), Q4.1 (G), R15.2
LED: IC3.5 (IO1), Q6.4 (S), RN6.8
unnamed: RN1.6, X6.3
unnamed: C15.2, IC3.20 (IO16), Q7.1, XT1.1
unnamed: C14.1, IC3.19 (IO15), Q7.2, XT1.2
unnamed: D4.4 (DIN), Q6.3 (D), RN6.7
unnamed: Q4.3 (D), X3.2, X5.2, X6.2
unnamed: Q2.3 (D), X12.4 (VCC)
unnamed: Q3.3 (D), X10.1
unnamed: Q5.3 (D), R22.2, X4.2
unnamed: RN1.5, X6.4
unnamed: RN1.8, X5.3
unnamed: RN1.7, X5.4
unnamed: RN3.5, X3.4
unnamed: RN3.6, X3.3
unnamed: RN3.8, X4.3
unnamed: RN3.7, X4.4
unnamed: RN4.6, RN5.7, RN5.8, X7.4, X8.4
unnamed: RN4.5, RN5.5, RN5.6, X7.3, X8.3
PD_ENABLE: D5.A, IC3.25 (IO21)
PD_SENSE: D5.C, IC3.18 (IO14), R17.2
QWIIC_SCL: IC3.36 (IO40), RN4.3
QWIIC_SDA: IC3.35 (IO39), RN4.4
REGOUT1: C24.2, IC7.10 (REGOUT)
SD_CS: IC3.14 (IO10), X12.2 (CD/DAT3)
SD_ENABLE: IC3.13 (IO9), Q2.1 (G)
SD_MISO: IC3.17 (IO13), R13.2, X12.7 (DAT0)
SD_MOSI: IC3.15 (IO11), X12.3 (CMD)
SD_SCLK: IC3.16 (IO12), X12.5 (CLK)
UART_ENABLE: IC3.26 (IO26), R21.1
UART_ENABLE1: Q5.1 (G), R16.2, R21.2
UART_RXD: IC3.40 (RXD0), RN3.1
UART_TXD: IC3.39 (TXD0), RN3.2
USB_D+: IC3.24 (IO20); also elsewhere on the board
USB_D-: IC3.23 (IO19); also elsewhere on the board
VCC_LED: C16.2, D4.1 (VCC), RN6.2, RN6.3, RN6.4; also elsewhere on the board
XBEE_CS: IC3.29 (IO34), X11.7
XBEE_ENABLE: IC3.37 (IO41), Q3.1 (G), R14.2
XBEE_INT: IC3.28 (IO33), X11.2
XBEE_MISO: IC3.33 (IO37), X10.4
XBEE_MOSI: IC3.31 (IO35), X11.1
XBEE_RESET: IC3.34 (IO38), X10.5
XBEE_RXD: IC3.22 (IO18), X10.2
XBEE_SCLK: IC3.32 (IO36), X11.8
XBEE_TXD: IC3.21 (IO17), X10.3

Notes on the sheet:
Connectors: I²C, UART, GPIO
IMU-Sensor
Light Sensor
Boot Switch
XBEE Socket
Micro SD Card
ESP32-S2-Mini
RGB LED

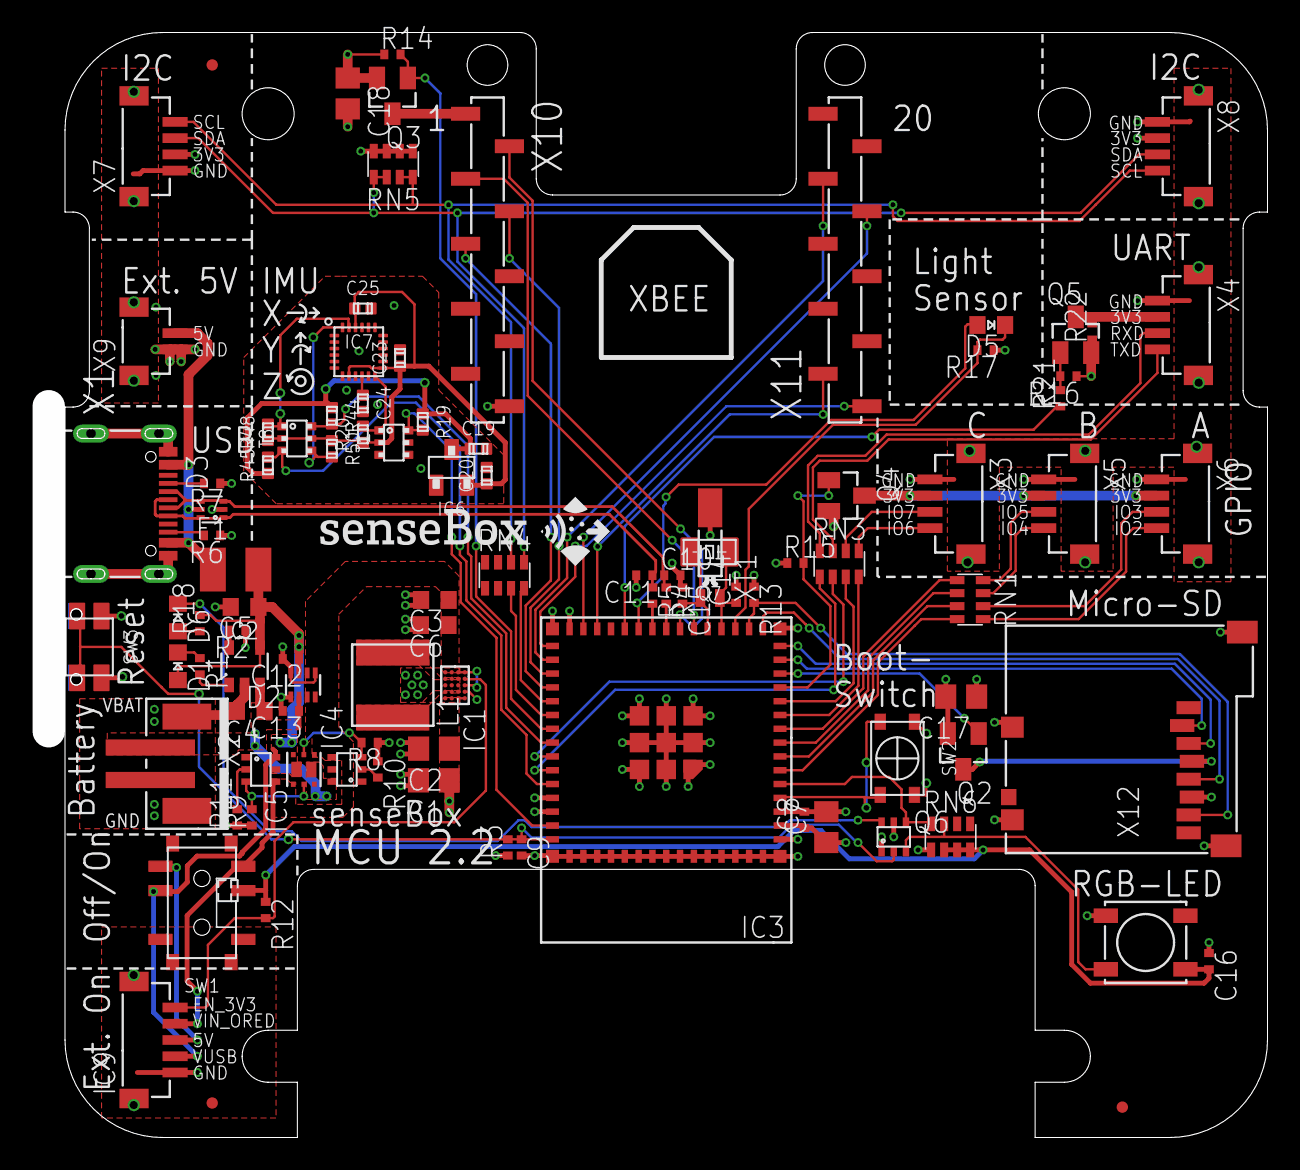
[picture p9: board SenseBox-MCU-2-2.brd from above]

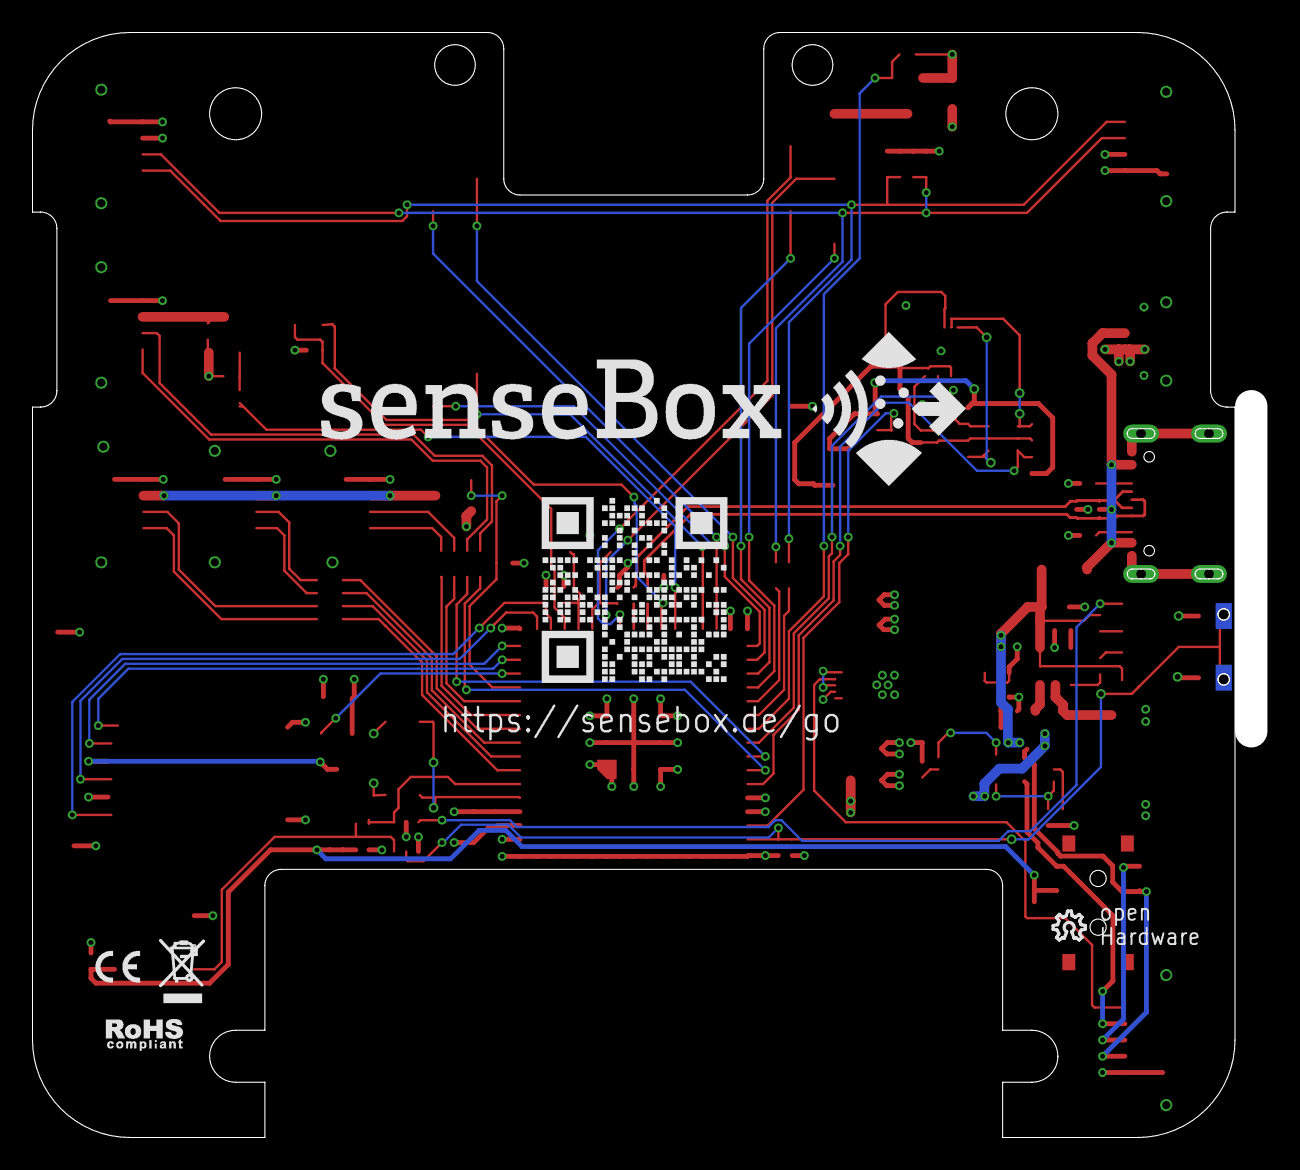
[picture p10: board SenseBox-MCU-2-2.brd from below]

Board: 4 copper layers, 75.0 x 68.0 mm, 102 parts (4 on the bottom side), 84 nets.

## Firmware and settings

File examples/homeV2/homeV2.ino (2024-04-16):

#include <ArduinoJson.h>
#include <Adafruit_HDC1000.h>
#include <sps30.h>
#include <Adafruit_DPS310.h>
#include <HttpClient.h>  // Install the ArduinoHttpClient library via Library Manager
#include <WiFi.h>
#include <ESPAsyncWebServer.h>
#include <hydreon.h>
#include "FS.h"
#include "SD.h"
#include "SPI.h"
#include "ids.h"
#include <Adafruit_LTR329_LTR303.h>
#include <Adafruit_VEML6070.h>
#include "esp_system.h"

const int wdtTimeout = 60000 * 2;  //time in ms to trigger the watchdog
hw_timer_t *timer = NULL;


// LTR
bool lightsensortype = -1;  //0 for tsl - 1 for ltr
unsigned char gain = 1;
unsigned char integrationTime = 0;
unsigned char measurementRate = 3;
// SPS30
uint32_t auto_clean_days = 4;
const long intervalsps = 1000;
unsigned long time_startsps = 0;
unsigned long time_actualsps = 0;
// Upload info
char serverAddress[] = "ingress.opensensemap.org";  // server address
int port = 80;
WiFiClient wifi;
HttpClient client = HttpClient(wifi, serverAddress, port);
int status = WL_IDLE_STATUS;
const char *ap_ssid = "senseBox-AccessPoint";
const char *ap_password = "123456789";

AsyncWebServer APserver(80);
// Sensr variables
Adafruit_HDC1000 hdc = Adafruit_HDC1000();
Adafruit_DPS310 dps;
HYDREON rg_15(Serial1);
Adafruit_VEML6070 veml = Adafruit_VEML6070();
Adafruit_LTR329 ltr = Adafruit_LTR329();
SPIClass sdspi = SPIClass();
// value variables
sensors_event_t temp_event, pressure_event;
float temperature, humidity, uv, lux;
struct sps30_measurement m;
static unsigned long previousMillis = 0;




const int bufferSize = 50;


String jsonString;
String ssidString;
String passwordString;

bool wifiConnected = false; 
bool sdMounted = false;

void ARDUINO_ISR_ATTR resetModule() {
  ets_printf("reboot\n");
  esp_restart();
}

void initSensors() {
  if (!hdc.begin()) {
    Serial.println("HDC error");
  }  // Initialize the DPS310 sensor
  if (!dps.begin_I2C(0x76)) {
    Serial.println("DPS310 error");
  } else {
    dps.configurePressure(DPS310_64HZ, DPS310_64SAMPLES);
    dps.configureTemperature(DPS310_64HZ, DPS310_64SAMPLES);
  }  
    // Initialize the VEML6070 sensor
  veml.begin(VEML6070_2_T);
  if (veml.readUV() == -1 || veml.readUV() == 65535) {
    Serial.println("VEML6070 error");
  }

  // Initialize the RG-15 sensor
  rg_15.begin();
  rg_15.readAllData();
  if (rg_15.getAccumulation() == -1) {
    Serial.println("RG-15 error");
  }

    if (!ltr.begin()) {
      Serial.println("LTR error");
  }
  else {
      ltr.setGain(LTR3XX_GAIN_2);
      ltr.setIntegrationTime(LTR3XX_INTEGTIME_100);
      ltr.setMeasurementRate(LTR3XX_MEASRATE_50);
  }
  if (veml.readUV() == -1 || veml.readUV() == 65535){
    Serial.println("VEML6070 error");
  }
  
  sensirion_i2c_init();
    int16_t ret;

  while (sps30_probe() != 0) {
    Serial.print("SPS sensor probing failed\n");
    delay(500);
  }
  Serial.print("SPS sensor probing successful\n");

  ret = sps30_set_fan_auto_cleaning_interval_days(auto_clean_days);
  if (ret) {
    Serial.print("error setting the auto-clean interval: ");
    Serial.println(ret);
  }

  ret = sps30_start_measurement();
  if (ret < 0) {
    Serial.print("error starting measurement\n");
  }


}


void setSensors() {
  getSPS30Data();
  dps.getEvents(&temp_event, &pressure_event);
  temperature = hdc.readTemperature();  
  humidity = hdc.readHumidity();
  rg_15.readAllData();
  uv =  veml.readUV();
  uint16_t ch1 = 0;
  uint16_t ch2 = 0;
  ltr.readBothChannels(ch1, ch2);
    lux = ch1;
}


void getSPS30Data() {
  uint16_t data_ready;
  int16_t ret;
  int attempts = 0;
  do {
    ret = sps30_read_data_ready(&data_ready);
    if (ret < 0) {
      Serial.print("error reading data-ready flag: ");
      Serial.println(ret);
    } else if (!data_ready) {
      Serial.print("data not ready, no new measurement available\n");
      attempts++;
      if (attempts >= 5) {
        Serial.println("Exceeded maximum attempts. Stopping.");
        break;
      }
    } else {
      break;
    }
    delay(100); /* retry in 100ms */
  } while (1);
  ret = sps30_read_measurement(&m);
}


String printSensorValuesJSON() {
  // Create a JSON document
  StaticJsonDocument<256> doc;

  // Add sensor values to the JSON document
  doc[TEMP_ID] = roundf(temperature * 10) / 10.0 ;
  doc[HUMI_ID] = roundf(humidity *10) / 10.0;
  doc[PRESSURE_ID] = roundf(pressure_event.pressure * 10) / 10.0;
  doc[LUX_ID] = roundf(lux * 10) / 10.0;
  doc[UV_ID] = roundf(uv * 10) / 10.0 ;
  doc[PM1_ID] = roundf(m.mc_1p0 * 10) / 10.0; // Rundet auf eine Nachkommastelle
  doc[PM25_ID] = roundf(m.mc_2p5 * 10) / 10.0; // Rundet auf eine Nachkommastelle
  doc[PM4_ID] = roundf(m.mc_4p0 * 10) / 10.0; // Rundet auf eine Nachkommastelle
  doc[PM10_ID] = roundf(m.mc_10p0 * 10) / 10.0; // Rundet auf eine Nachkommastelle
  doc[RAINEVENT_ID] = roundf(rg_15.getEventAccumulation() * 10) /10.0;
  doc[RAININTENSITY_ID] = roundf(rg_15.getRainfallIntensity() * 10) / 10.0 ;
  doc[RAINTOTALACC_ID] = roundf(rg_15.getTotalAccumulation() * 10) / 10.0;

  // Serialize the JSON document to a string
  serializeJson(doc, jsonString);

  return jsonString;
  // Send JSON data to OpenSenseMap API
}


void sendToOpenSenseMap(String data) {
  // Überprüfen Sie den Status der WLAN-Verbindung
  if (WiFi.status() != WL_CONNECTED) {
    Serial.println("No WLAN connection available. Cannot send data.");
    return; // Beenden Sie die Funktion, wenn keine WLAN-Verbindung besteht
  }
  // Prepare headers
  String contentType = "application/json";
  String url = "/boxes/" + String(SENSEBOX_ID) + "/data";
  Serial.println("Making POST request");
  Serial.println(contentType);
  Serial.println(url);
  Serial.println(data);
  client.post(url, contentType, data);

  // Read the status code and body of the response
  int statusCode = client.responseStatusCode();
  String response = client.responseBody();

  Serial.print("Status code: ");
  Serial.println(statusCode);
  Serial.print("Response: ");
  Serial.println(response);
}


void readWiFi(fs::FS &fs, const char *path) {
  size_t maxLen = 100;
    Serial.println("Reading WiFi Information:");
  File file = fs.open("/wifi.cfg");
  String tmp;
  if (file) {
    while (file.available()) {
      char c = file.read();
        tmp += c;
    }
    file.close();
  }
  else {
    Serial.println("Failed to open file for reading");
  }
  tmp.trim();
  tmp = decryptString(tmp);
  splitStringByComma(tmp, ssidString, passwordString);

  }

void updateWiFiConnection(fs::FS &fs, String newSSID, String newPassword) {
  // Versuche, die Verbindung zu aktualisieren, ohne die aktuelle Verbindung zu trennen
   Serial.println("Updating WiFi Information:");
   Serial.print("New SSID: ");
    Serial.println(newSSID);
    Serial.print("New Password: ");
    Serial.println(newPassword);
  newSSID.trim();
  String newWifi = newSSID + "," + newPassword;
  newWifi = encryptString(newWifi);
  char newWifiArray[newWifi.length() + 1];
  newWifi.toCharArray(newWifiArray, newWifi.length() + 1);
  Serial.println(newWifiArray);
  File wifiFile = fs.open("/wifi.cfg", FILE_WRITE);
  if (!wifiFile) {
    Serial.println("Failed to open file for writing");
    return;
  }
  wifiFile.println(newWifi);
  wifiFile.close();
  Serial.println("Updated WiFi Information");
}


void setup() {

  // setup watchdog 
  timer = timerBegin(0, 80, true);                   //timer 0, div 80
  timerAttachInterrupt(timer, &resetModule, true);   //attach callback
  timerAlarmWrite(timer, wdtTimeout * 1000, false);  //set time in us
  timerAlarmEnable(timer);                           //enable interrupt

  // Enable SD 
  pinMode(SD_ENABLE, OUTPUT);
  digitalWrite(SD_ENABLE, LOW);
  delay(2000);
  sdspi.begin(VSPI_SCLK, VSPI_MISO, VSPI_MOSI, VSPI_SS);
  if (!SD.begin(VSPI_SS, sdspi)) {
    Serial.println("Card Mount Failed");
  }
  else {
    sdMounted = true;
  }
  WiFi.softAP(ap_ssid, ap_password);
  // Set WiFi configs based on SD readings
  readWiFi(SD, "/wifi.cfg");
  // Setze Routen für den Webserver
  APserver.on("/", HTTP_GET, [](AsyncWebServerRequest *request) {
    // Lese den aktuellen WiFi-Status
    String html = buildHTMLString();
    // Sende die HTML-Seite an den Cient
    request->send(200, "text/html", html);
  });

  // Route für das Speichern der SSID und des Passworts
  APserver.on("/save", HTTP_POST, [](AsyncWebServerRequest *request) {
    // Lese die Werte von den Formulareingaben
    // Versuche, zur neuen SSID zu verbinden
    updateWiFiConnection(SD, request->arg("ssid"), request->arg("password"));
    // Antworte dem Client mit einer Bestätigungsseite
    String saveHtml = buildSaveString();
    request->send(200, "text/html", saveHtml);
    delay(5000);
    esp_restart();
  });
  
  APserver.begin();
  Serial.println("Init sensors");
  initSensors();
  Serial.println("Set sensors");
  setSensors();
  Serial.println("Connecting to WiFi");
  Serial.print("SSID: ");
  Serial.println(ssidString);
  Serial.print("Password: ");
  Serial.println(passwordString);
  WiFi.begin(ssidString.c_str(), passwordString.c_str());

  // Warte, bis die Verbindung hergestellt ist
  unsigned long previousMillisWifi = 0;
  while (WiFi.status() != WL_CONNECTED) {
    unsigned long currentMillisWifi = millis();
    // Überprüfe, ob das Intervall vergangen ist
    if (currentMillisWifi - previousMillisWifi >= 5000) {
      // Speichere die aktuelle Zeit als Referenz für das nächste Intervall
      Serial.println("Connecting to WiFi...");
      previousMillisWifi = currentMillisWifi;
      // Führe die Verbindungskontrolle aus
    }
  }
  Serial.println("Connected to WiFi");
  wifiConnected= true;
}

void loop() {

  // Check if 60 seconds have passed
  const long interval = 300000 ;  // 5 Minutes
  unsigned long currentMillis = millis();
  timerWrite(timer, 0);  //reset timer (feed watchdog)

  if (currentMillis - previousMillis >= interval || previousMillis == 0) {
    wifiConnected = WiFi.status() == WL_CONNECTED;
    setSensors();
    // Print sensor values in JSON format
    jsonString = printSensorValuesJSON();
    sendToOpenSenseMap(jsonString);
    // Reset the timer
    previousMillis = currentMillis;
  }

  // Add any other code for your application here
}

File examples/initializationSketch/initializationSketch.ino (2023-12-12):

#include <Adafruit_NeoPixel.h>
#include <Adafruit_MPU6050.h>
#include <Wire.h>
#include <WiFi.h>
#include <WiFiMulti.h>
#include <Adafruit_SSD1306.h>
#include "SD.h"
#include "SPI.h"

// display defines
#define SCREEN_WIDTH 128
#define SCREEN_HEIGHT 64
#define OLED_RESET -1

char testVersion[] = "1.0";

// Object declaration
Adafruit_SSD1306 display(SCREEN_WIDTH, SCREEN_HEIGHT, &Wire, OLED_RESET);
Adafruit_NeoPixel rgb_led(1, PIN_NEOPIXEL, NEO_GRB + NEO_KHZ800);
Adafruit_MPU6050 mpu;
WiFiMulti WiFiMulti;
WiFiServer server(80);


// Variables for tests
bool pdTestPassed = false;
bool mpuTestPassed = false;
bool wifiTestPassed = false;
bool displayTestPassed = false;
bool sdTestPassed = false;

int deviceCount = 0; 
IPAddress accessPointIP;
// MPU
sensors_event_t a, g, temp;
// PD
int pdTestValue = 0;
// Array to hold all connected I2C devices
const int maxDevices = 128; // Maximale Anzahl möglicher I2C-Adressen
byte deviceAddresses[maxDevices];
// interval for display page change
const long intervalInterval = 5000;
long time_startInterval = 0;
long time_actualInterval = 0;
// counter for which page which is displayed
int displayPage = 0;
int fileCounter = 0;
// ssid and pass for the access point
char ssid[] = "sensebox"; 
char pass[] = "sensebox";


unsigned long getUptimeInSeconds() {
  return millis() / 1000;
}


void displayCheck() {
  Wire.begin();
  byte error;
  Wire.beginTransmission(0x3D);
  error = Wire.endTransmission();
  if (error != 0){
    Serial.println("Display nicht gefunden!");
    return;
  }
  display.begin(SSD1306_SWITCHCAPVCC, 0x3D);
  display.display();
  Serial.println("Display gefunden!");
  displayTestPassed = true;
  delay(1000);
}

void displayTestResults() {
  display.clearDisplay();
  display.setCursor(0,0);
  display.setTextSize(1);
  display.setTextColor(WHITE,BLACK);
  
  display.println("MPU Test: ");
  if (mpuTestPassed)
    display.println("Erfolgreich!");
  else
    display.println("Fehlgeschlagen!");
  
  display.println(" ");

  display.println("Photodiode Test: ");
  if (pdTestPassed)
    display.println("Erfolgreich!");
  else
    display.println("Fehlgeschlagen!");
  
  display.println(" ");

  display.println("Wifi Test: ");
    if (wifiTestPassed)
    display.println("Erfolgreich!");
  else
    display.println("Fehlgeschlagen!");
  display.display();
}

void displayI2CResults() {
  display.clearDisplay();
  display.setCursor(0,0);
  display.setTextSize(1);
  display.setTextColor(WHITE,BLACK);
  display.println("Suche nach Geraeten... ");
  display.display();
}

void displayWifiStatus(){
  if(wifiTestPassed) {
    display.clearDisplay();
    display.setCursor(0,0);
    display.setTextSize(1);
    display.setTextColor(WHITE,BLACK);
    display.print("SSID: "); 
    display.println(ssid); 
    display.print("Password: "); 
    display.println(pass);
    display.println("Server erreichbar unter: ");
    display.println(accessPointIP);
  }
  else {
    display.println("WiFi Test fehlgeschlagen!"); 
  }
  display.display();  

}

void displayUptimeAndSDCard(){
  display.clearDisplay();
  display.setCursor(0,0);
  display.setTextSize(1);
  display.setTextColor(WHITE,BLACK);
  display.print("Zeit seit dem Hochfahren:"); 
  display.println(millis());
  display.print("SD Karte: "); 
  if(!sdTestPassed) {
    display.println("Keine SD Karte eingesteckt"); 
  }
  else{
    display.print(fileCounter);
    display.println(" Dateien gefunden.");
  }
  display.display();
}
void displayI2CCount() {
  display.clearDisplay();
  display.setCursor(0,0);
  display.setTextSize(1);
  display.setTextColor(WHITE,BLACK);
  display.println("Suche nach Geraeten..");
  for (int i = 0; i < deviceCount; i++) {
    display.printf("0x%02X", deviceAddresses[i]);
    if(i != deviceCount - 1) {
      display.print(", "); 
    }
  }
  display.display();
}

void countI2cDevices () {
  byte error, address;
    Serial.println("Scannen nach I2C Geraeten ...");
  for(address = 0x01; address < 0x7f; address++){
    Wire.beginTransmission(address);
    error = Wire.endTransmission();
    if (error == 0){
      Serial.printf("I2C Geraet gefunden an 0x%02X\n", address);
      deviceAddresses[deviceCount++] = address;
    } else if(error != 2){
      Serial.printf("Fehler %d an 0x%02X\n", error, address);
    }
  }
  if (deviceCount == 0){
    Serial.println("Kein I2C Geraet gefunden!");
  }
}

void sdTest(){
  // enable SD module
  pinMode(SD_ENABLE, OUTPUT);
  digitalWrite(SD_ENABLE,LOW);
  SPIClass sdspi = SPIClass();
  sdspi.begin(VSPI_SCLK,VSPI_MISO,VSPI_MOSI,VSPI_SS);
  if(!SD.begin(VSPI_SS,sdspi)){
        Serial.println("Keine SD Karte gefunden!");
        return;
    }

  if(!SD.begin(VSPI_SS,sdspi)){
    Serial.println("Keine SD Karte gefunden!");
    return; 
  }
  uint8_t cardType = SD.cardType(); 
  
  if (cardType == CARD_NONE){
    Serial.println("Keine SD Karte gefunden"); 
    return;
  }

  Serial.println("SD Karte erfolgreich initiiert!");
  File root = SD.open("/");
  // Lese alle Dateien im Stammverzeichnis und gebe ihre Namen aus
  while (true) {
    File entry = root.openNextFile();
    if (!entry) {
      // Es gibt keine weiteren Dateien
      break;
    }
    if(entry.name() != "System Volume Information") {
      fileCounter++;
      Serial.print("Datei gefunden: ");
      Serial.println(entry.name());
    }
    entry.close();

  }
  sdTestPassed = true; 
  return; 
}

void mpuTest() {
  Wire1.begin();

  if (!mpu.begin(0x68, &Wire1)) {
    Serial.println("MPU6050 Chip wurde nicht gefunden");
    return;
  }

  Serial.println("MPU6050 gefunden!");
  mpu.setAccelerometerRange(MPU6050_RANGE_8_G);
  mpu.setGyroRange(MPU6050_RANGE_500_DEG);
  mpu.getEvent(&a, &g, &temp);

  Serial.println("Beschleunigungswerte:");
  Serial.print(a.acceleration.x);
  Serial.print(" ");
  Serial.print(a.acceleration.y);
  Serial.print(" ");
  Serial.println(a.acceleration.z);

  if (a.acceleration.x == 0 && a.acceleration.y == 0 && a.acceleration.z == 0) {
    return;
  }

  mpuTestPassed = true;
}

void pdTest() {
  pinMode(PD_ENABLE, OUTPUT);
  analogReadResolution(12);
  digitalWrite(PD_ENABLE, HIGH);

  int count = 0;
  int totalValues = 0;

  while (count < 20) {
    uint16_t value = analogRead(PD_SENSE);
    totalValues += value;
    count++;
  }
  pdTestValue = totalValues / count;
  if (pdTestValue == 0) {
    Serial.println("Photodiode-Test nicht bestanden!!");
    return;
  }

  Serial.println("Photodiode Test erfolgreich!");
  pdTestPassed = true;
}

void wifiTest() {
  if (!WiFi.softAP(ssid, pass)) {
    Serial.println("WiFi-Test fehlgeschlagen.");
    return;
  }

  accessPointIP = WiFi.softAPIP();
  server.begin();
  Serial.println("Gerät erreichbar unter: ");
  Serial.print("AP IP Adresse: ");
  Serial.println(accessPointIP);
  wifiTestPassed = true;

}
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

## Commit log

2023-08-17 add examples, hardwarefiles and first doku
    [SenseBox-MCU-2-0.brd, SenseBox-MCU-2-0.sch, SenseBox-MCU-2-1.brd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]
2023-10-17 add 2.1 schematics pdf
2023-10-25 vl53l8cx with led matrix example
2023-12-18 Update SMT50.ino
    Fix reference voltage by using analogReadMilliVolts and set read resolution to 13bit.
    [SMT50.ino]
2024-02-19 led matrix: generated fire example
2025-06-23 add 2.2 schematics
    [SenseBox-MCU-2-2.brd, SenseBox-MCU-2-2.sch]
